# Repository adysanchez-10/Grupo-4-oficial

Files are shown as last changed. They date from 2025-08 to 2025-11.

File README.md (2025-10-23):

# Integrantes del Proyecto

## Camila Andrea Seijas Rojas
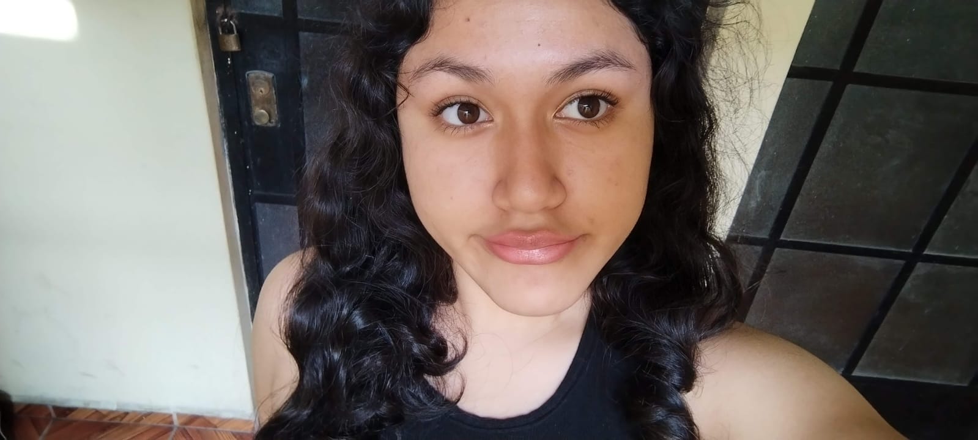
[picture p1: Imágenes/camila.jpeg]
## 
- **Edad:** 18 años  
- **Información personal:** Interés en el área de biomecánica y rehabilitación.  
- **Rol:** Investigación y redacción  
- **Responsabilidades:**
  - Seleccionar la información pertinente y necesaria  
  - Editar la información en GitHub  

---

## Milagros Mariajosé Rodriguéz Solano
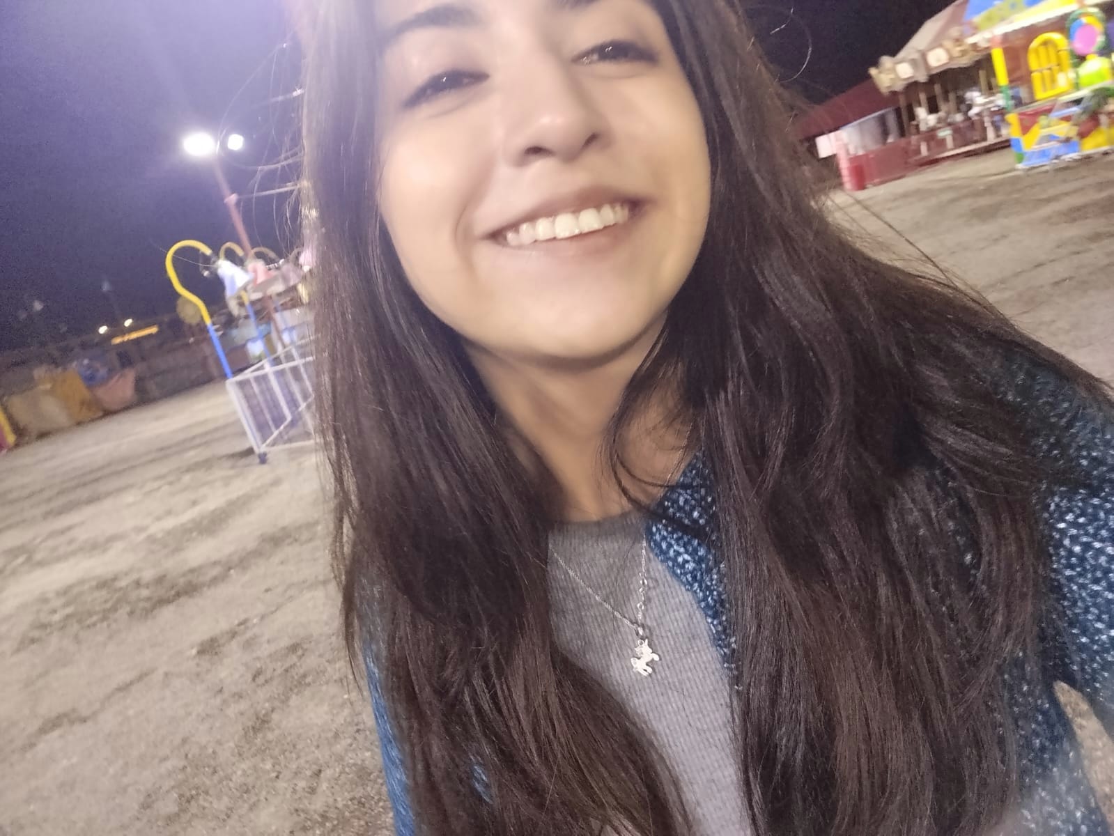
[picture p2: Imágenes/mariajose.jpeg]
## 
- **Edad:** 20 años  
- **Información personal:** Interés en el área de biomecánica y rehabilitación.  
- **Rol:** Modelador 3D  
- **Responsabilidades:**
  - Optimización de modelos  
  - Diseño y construcción de modelos 3D  

---

## Rodrigo Emiliano Salas Cano
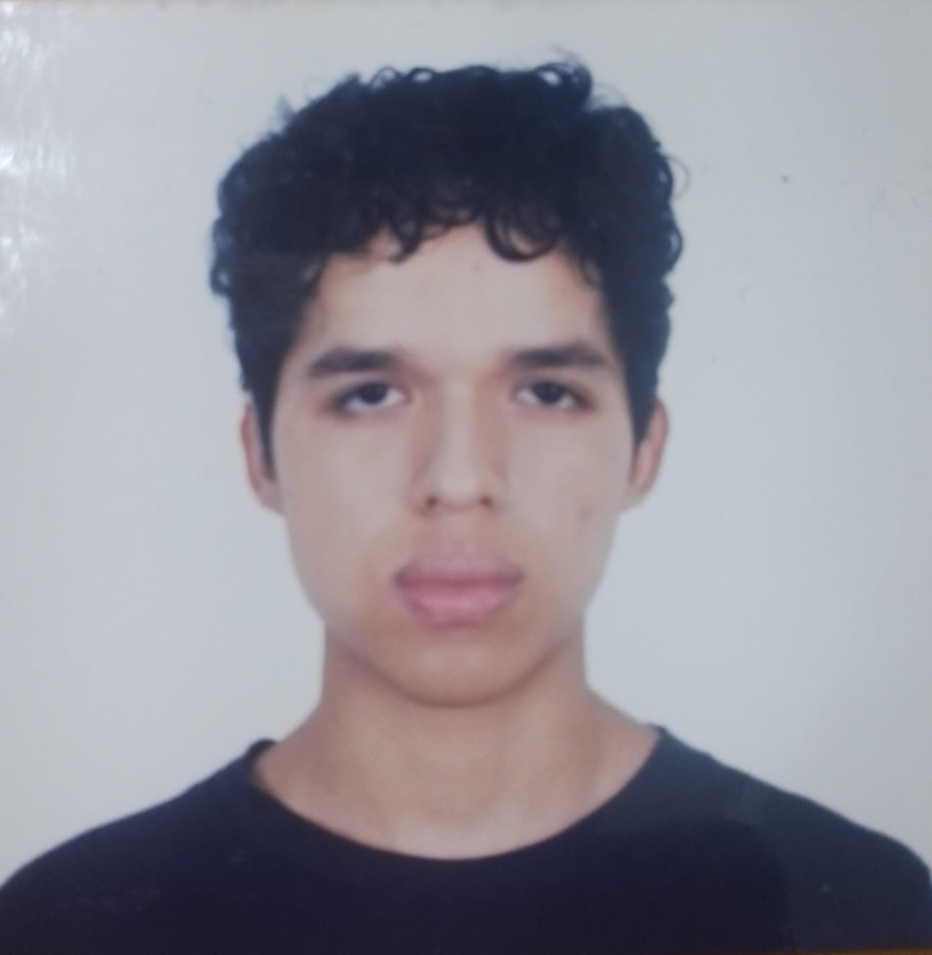
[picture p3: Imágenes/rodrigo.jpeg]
## 
- **Edad:** 18 años  
- **Información personal:** Interés en el área de tejidos.  
- **Rol:** Gestor de repositorio de GitHub  
- **Responsabilidades:**
  - Control de calidad del código  
  - Gestión de problemas  

---

## Gabriel Romero Guerrero
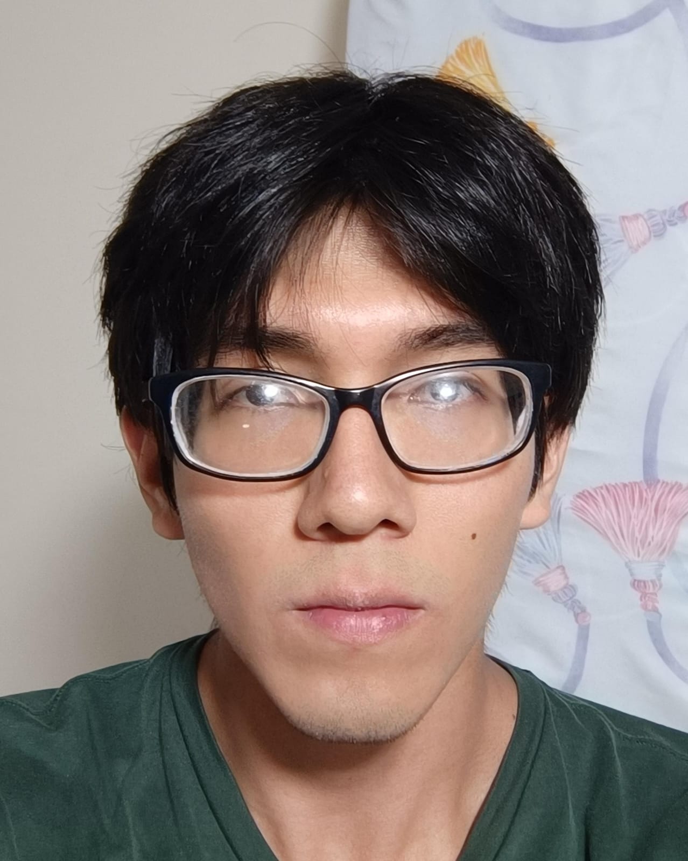
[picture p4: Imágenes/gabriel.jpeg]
## 
- **Edad:** 23 años  
- **Información personal:** Interesado en la aplicación de la tecnología para problemas biomecánicos y de diagnóstico.  
- **Rol:** Funcionamiento de la electrónica  
- **Responsabilidades:**
  - Cableado y conexionado  
  - Diseño y modificación de circuitos  

---
## Ady Sebastián Sánchez Guevara
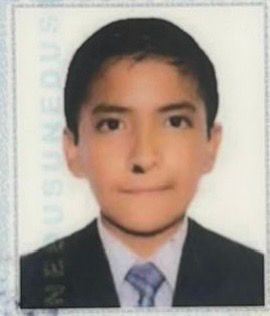
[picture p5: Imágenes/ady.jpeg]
## 
- **Edad:** 18 años  
- **Información personal:** Interés en el área de clínica.  
- **Rol:** Programación  
- **Responsabilidades:**
  - Crear las carpetas en GitHub  
  - Editar la información en GitHub  

---

## Leonardo Romani León}
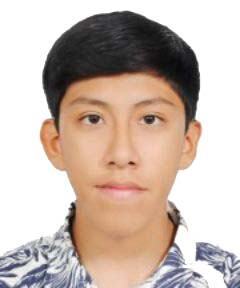
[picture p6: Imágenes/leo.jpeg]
## 
- **Edad:** 18 años  
- **Información personal:** Interés en el área de biomecánica en imágenes.  
- **Rol:** Programación y modelo 3D  
- **Responsabilidades:**
  - Elaboración de código para el funcionamiento del mecanismo  
  - Elaboración del modelado en 3D

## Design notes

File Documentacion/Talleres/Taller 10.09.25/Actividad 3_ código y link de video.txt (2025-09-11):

Link de video en Youtube: https://youtube.com/shorts/MGsZXVsQCxA?si=Kkdt9dwiiTKEzWkI

//inicio de código
#include <MPU6050.h>
#include <Wire.h>

MPU6050 mpu;

const int buzzerPin = 8;
const float g = 9.81;  // gravedad en m/s^2
const float umbralCaidaAlta = 2.0 * g;   // > 2g
const float umbralCaidaBaja = 0.5 * g;   // caída libre ~0.5g

bool alarmaActiva = false;
unsigned long tiempoInicioAlarma = 0;   
const unsigned long duracionAlarma = 2000; // 5 segundos

void setup() {
  Serial.begin(9600);
  Wire.begin();
  mpu.initialize();

  if (mpu.testConnection()) {
    Serial.println("MPU6050 conectado correctamente.");
  } else {
    Serial.println("Error al conectar MPU6050.");
  }

  pinMode(buzzerPin, OUTPUT);
  digitalWrite (8,HIGH);
}

void loop() {
  int16_t ax, ay, az;
  mpu.getAcceleration(&ax, &ay, &az);

  // Convertir a m/s^2 (rango configurado en ±2g)
  float ax_g = ax / 16384.0 * g;
  float ay_g = ay / 16384.0 * g;
  float az_g = az / 16384.0 * g;

  // Magnitud total de la aceleración
  float aTotal = sqrt(ax_g * ax_g + ay_g * ay_g + az_g * az_g);

  Serial.print("aTotal = ");
  Serial.println(aTotal);

  // Detectar caída y activar buzzer
  if (!alarmaActiva && (aTotal > umbralCaidaAlta || aTotal < umbralCaidaBaja)) { //alta 19.62 baja 4.9
    Serial.println("¡Caída detectada!");
    tone(buzzerPin, 3000);        // sonido de alerta
    alarmaActiva = true;
    tiempoInicioAlarma = millis(); // guardamos el momento
  }

  // Apagar buzzer después de 5 segundos
  if (alarmaActiva && (millis() - tiempoInicioAlarma >= duracionAlarma)) {
    noTone(buzzerPin);
    digitalWrite(8,HIGH);
    alarmaActiva = false;
    Serial.println("Alarma apagada automáticamente.");
  }
 
  delay(200);
}
//fin

3RO

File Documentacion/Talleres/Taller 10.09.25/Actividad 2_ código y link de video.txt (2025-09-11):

Link de video en Youtube: https://youtube.com/shorts/js4WZ6bAnnM?si=TciuPzV8fLwrm0xc

//inicio de código usado
// Pines de sensores
const int flexPin = A0;
const int fsr1Pin = A1;
const int fsr2Pin = A2;

// Pines de LEDs
const int ledVerde = 9;   // PWM
const int ledRojo = 8;
const int ledAmarillo = 7;

// Umbrales para los FSR (ajustar tras calibración)
const int umbralFSR1 = 300;  
const int umbralFSR2 = 300;  

void setup() {
  pinMode(ledVerde, OUTPUT);
  pinMode(ledRojo, OUTPUT);
  pinMode(ledAmarillo, OUTPUT);
  
  Serial.begin(9600);
}

void loop() {
  // Lecturas analógicas
  int flexValue = analogRead(flexPin);
  int fsr1Value = analogRead(fsr1Pin);
  int fsr2Value = analogRead(fsr2Pin);

  // --- LED verde con PWM proporcional a la flexión ---
  int brillo = map(flexValue, 0, 1023, 0, 255);
  analogWrite(ledVerde, brillo);

  // --- LED rojo controlado por FSR1 ---
  if (fsr1Value > umbralFSR1) {
    digitalWrite(ledRojo, HIGH);
  } else {
    digitalWrite(ledRojo, LOW);
  }

  // --- LED amarillo controlado por FSR2 ---
  if (fsr2Value > umbralFSR2) {
    digitalWrite(ledAmarillo, HIGH);
  } else {
    digitalWrite(ledAmarillo, LOW);
  }

  // Enviar datos al monitor serie
  Serial.print("Flex: "); Serial.print(flexValue);
  Serial.print(" | FSR1: "); Serial.print(fsr1Value);
  Serial.print(" | FSR2: "); Serial.println(fsr2Value);

  delay(50); // pequeña pausa
}
//fin

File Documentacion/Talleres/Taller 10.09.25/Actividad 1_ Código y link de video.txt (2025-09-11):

Link de video en Youtube: https://youtu.be/Luw4oxsUc28?si=Q1tBcIxFa8vk1GIK

//inicio de código utilizado
const int emgPin = A0;
const int ledpin = 13;
int umbral = 350;

void setup() {
  Serial.begin(9600);
  pinMode(ledpin, OUTPUT);
}

void loop() {
  int emgValue = analogRead(emgPin); // Lectura del sensor

  if (emgValue > umbral) {
    digitalWrite(ledpin, HIGH); // Enciende el LED si se supera el umbral
  } else {
    digitalWrite(ledpin, LOW);  // Apaga el LED si no se supera
  }

  Serial.print("EMG Value: ");
  Serial.println(emgValue);

  delay(100);
}
//fin

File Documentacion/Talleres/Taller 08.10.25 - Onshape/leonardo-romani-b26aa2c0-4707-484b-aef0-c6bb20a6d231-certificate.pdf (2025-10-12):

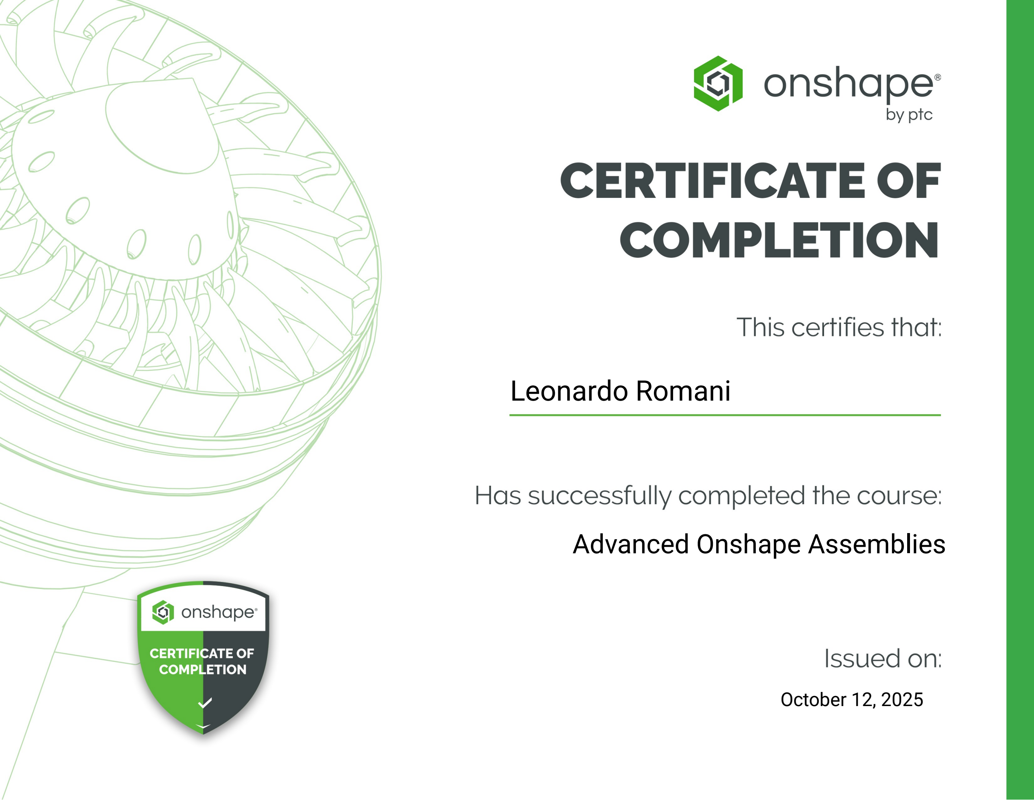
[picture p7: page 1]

Leonardo Romani

Advanced Onshape Assemblies

October 12, 2025

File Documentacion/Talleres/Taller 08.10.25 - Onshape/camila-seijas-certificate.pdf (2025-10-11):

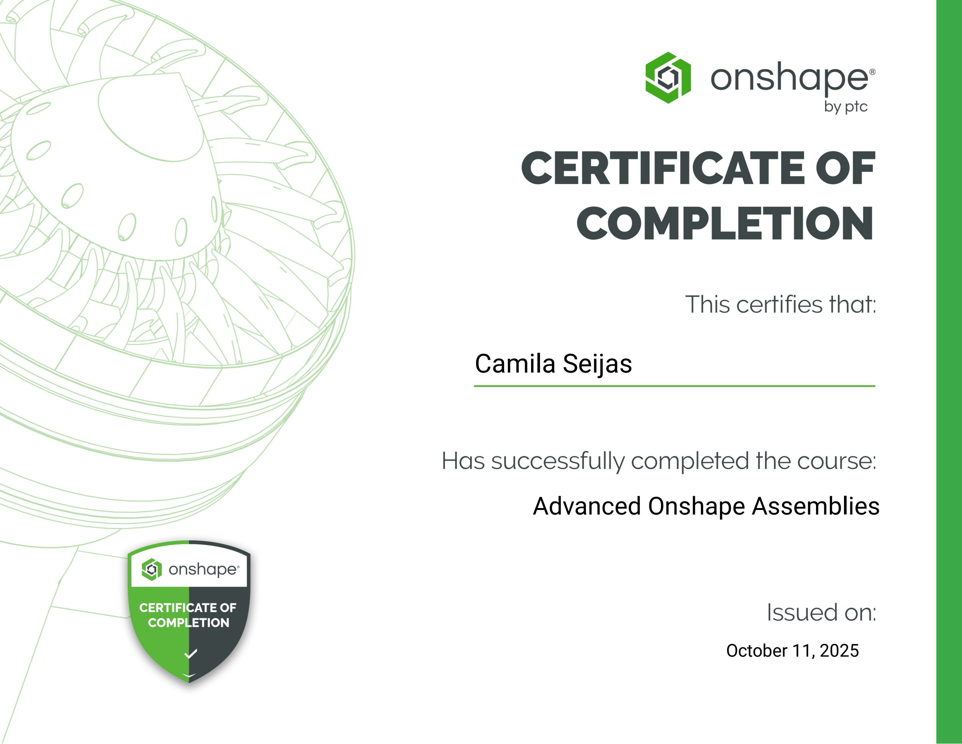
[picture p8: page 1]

Camila Seijas

Advanced Onshape Assemblies

October 11, 2025

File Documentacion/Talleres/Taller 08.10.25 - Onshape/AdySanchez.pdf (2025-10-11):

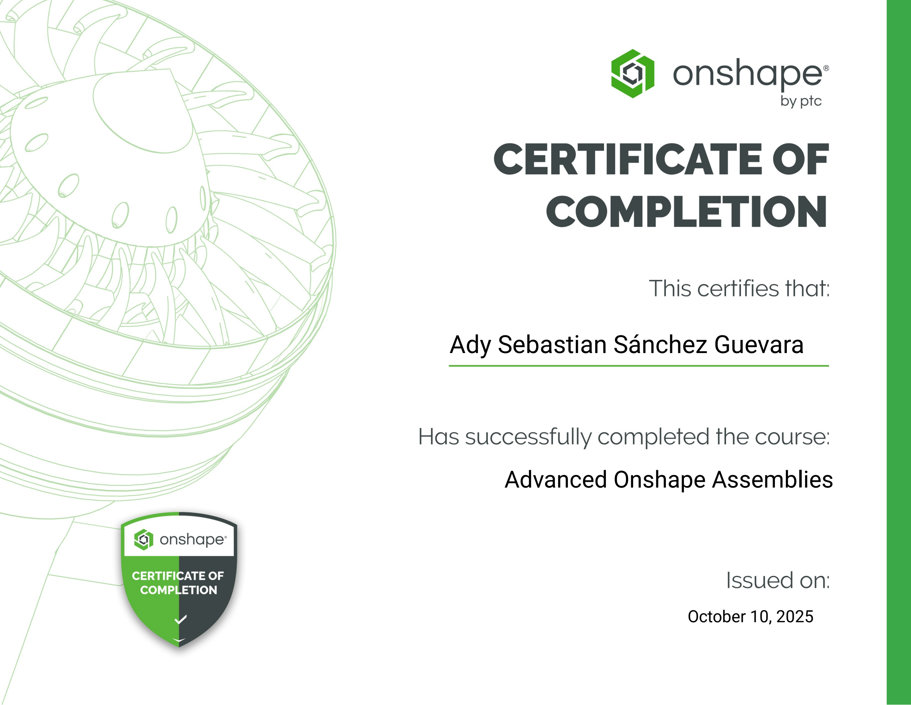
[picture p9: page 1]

Ady Sebastian Sánchez Guevara

Advanced Onshape Assemblies

October 10, 2025

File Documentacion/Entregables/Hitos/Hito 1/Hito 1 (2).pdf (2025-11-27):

# FOMEX Grupo 04

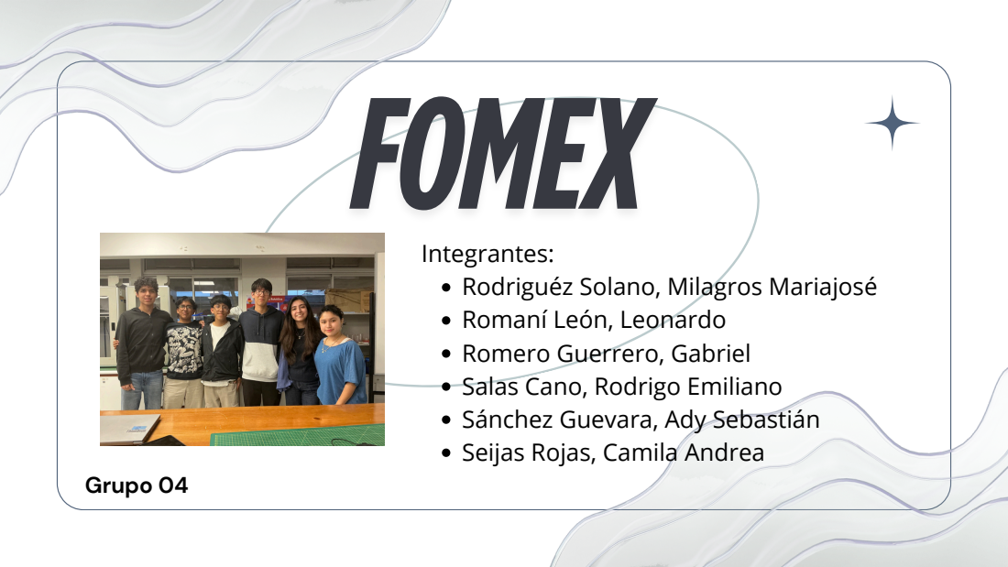
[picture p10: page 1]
s: Rodrigué; ola; Mila; ria; tiá; eij; mila

riel Salas Cano, Rodrigo Emilia

# CONTEXTO DEL CASO

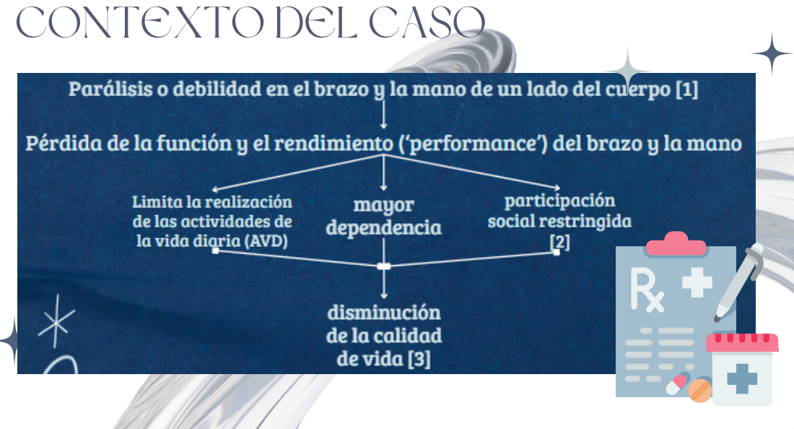
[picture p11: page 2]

# CONTEXTO DEL CASO

## 87 % de los pacientes reporta que experimenta al desuso de su mano y brazo afectado

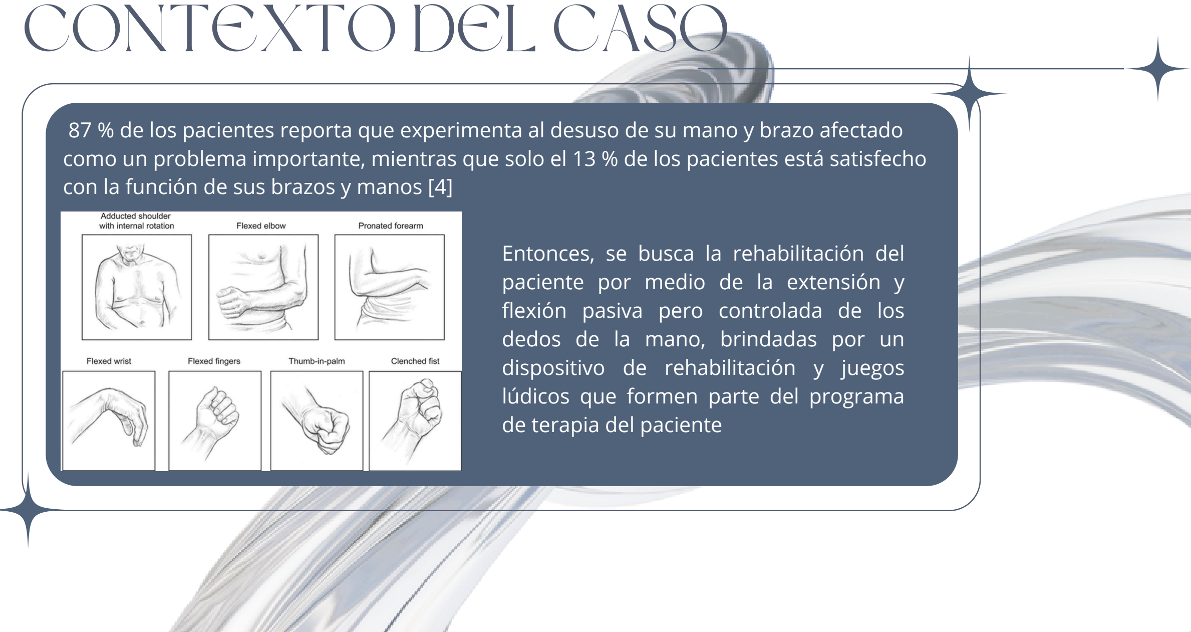
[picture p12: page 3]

## como un problema importante, mientras que solo el 13 % de los pacientes está satisfecho con la función de sus brazos y manos [4]

## Entonces, se busca la rehabilitación del paciente por medio de la extensión y flexión pasiva pero controlada de los dedos de la mano, brindadas por un dispositivo de rehabilitación y juegos lúdicos que formen parte del programa de terapia del paciente

# CONTEXTO DEL CASO

## Descripción del ACV:

## El Accidente Cerebrovascular (ACV), también conocido como ictus o derrame cerebral, es

una alteración súbita del flujo sanguíneo hacia una parte del cerebro.

## Cuando esto ocurre, las neuronas dejan de recibir oxígeno y nutrientes, provocando la

muerte de las células cerebrales en pocos minutos [5].

## Descripción del caso: Paciente femenina de 55 años con hemiplejia espástica derecha post-ACV

## Presenta leve disartria y marcha insegura (deambula con bastón de 4 apoyos) Comprensión y cognición conservadas

Funcionalidad completa del hemicuerpo izquierdo [6].

## Rehabilitación:

## Terapia física, 3 veces por semana (ejercicios de movilidad, estiramientos y reeducación

de la marcha).
Terapia de lenguaje, 1 vez por semana (manejo de disartria leve) [6].

# ESTADO DEL ARTE

# 1.PATENTE: Órtesis robótica PRO-DWix® (PCT/CO2017/000006)

Objetivo:
Complementar la rehabilitación y mejorar la adherencia de los pacientes con espasticidad de mano post ACV o tras una lesión medular con un dispositivo para uso domiciliario

## Funcionamiento: El dispositivo mueve la mano del paciente mediante un sistema de servomotores y piezas articuladas que actúan como un exoesqueleto

Motores en la Mano: Sobre el dorso de la
mano del paciente se colocan unos servomotores.
Sistema de Palancas: Cada servomotor está conectado a un sistema de palancas hechas de acrílico. Estas palancas están unidas a los dedos del paciente mediante unas correas. Acción de Flexión y Extensión: Cuando los motores se activan, giran y mueven la primera palanca. Este movimiento se transmite a las otras piezas articuladas, obligando a los dedos a doblarse (flexión) y estirarse (extensión) de manera controlada y armónica, imitando el movimiento natural de las articulaciones.

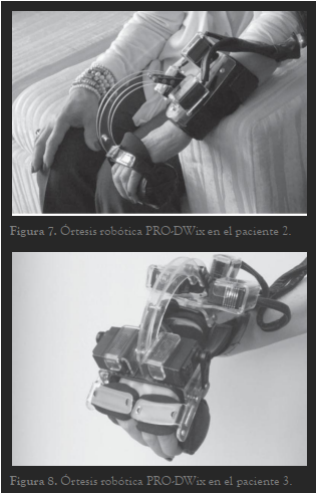
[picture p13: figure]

Fuentes:

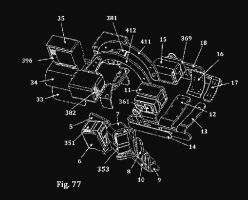
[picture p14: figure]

[7] J. D. Moreno Arango and J. A. Moreno Arango, "Ortesis robóticas para rehabilitación de mano y muñeca," PCT Int. Appl. WO 2018/036571 A1, Mar. 1, 2018.
[8] J. F. Gómez-Rendón, J. D. Moreno-Arango, J. M. Medina-Salcedo, J. Becerra-Velásquez, G. A. Gil-Henao, and M. A. Gil-Guerrero, "Rehabilitación robótica en espasticidad de mano y muñeca," Rev. Col. Med. Fis. Rehab., vol. 30, no. 2, pp. 103-115, 2020. doi: 10.28957/rcmfr.v30n2.

# 2. PROTOTIPO BASADO EN ARTÍCULO CIENTÍFICO: DexoHand

Objetivo:
Complementar la rehabilitación de los pacientes con espasticidad de mano post ACV Sistema de accionamiento por cables: aligera el peso (recomendación de 230 g a menos de masa sobre la mano [9])
Movimiento Anatómicamente Preciso: El exoesqueleto está diseñado para que sus centros de rotación virtual coincidan con las articulaciones reales de los dedos del paciente (MCP, PIP, DIP).

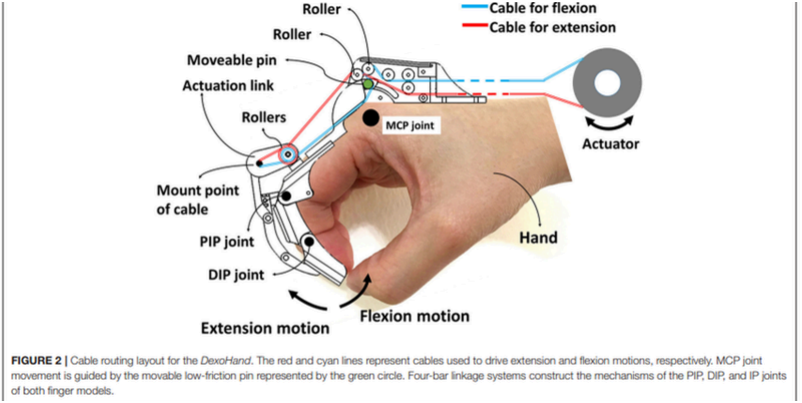
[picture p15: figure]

Fuente: [9] Y.-L. Tsai et al., "Usability Assessment of a Cable-Driven Exoskeletal Robot for Hand Rehabilitation," Front. Neurorobot., vol. 13, Art. no. 3, Feb. 2019, doi: 10.3389/fnbot.2019.00003.

### “Los cables eran accionados por un servomotor (motor BLDC, fuerza = 0,014

N-m, Faulhaber GmbH & Co. KG,

### Schönaich, Alemania) acoplado a un desacelerador (relación de transmisión = 1:100). A través del desacelerador, el

## torque de salida (con respecto a las articulaciones MCP de cada dedo) podía alcanzar hasta 1,4 N-m, lo que producía

### una fuerza de flexión y extensión correspondiente de 145 y 112 N. Según nuestras estimaciones, este nivel de

## fuerza pico es adecuado para manipular los dedos con MAS ≦ 3.”

## Torque pico de salida (con respecto a las articulaciones MCP de cada dedo) debe alcanzar hasta 1,4 Nm para manipular los dedos de manos con MAS ≦ 3, como la paciente del caso

## No extiende el pulgar

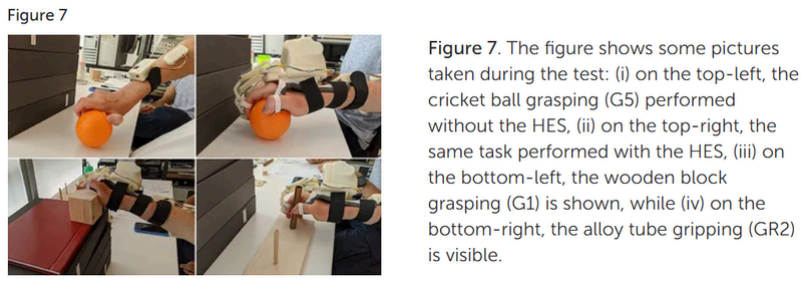
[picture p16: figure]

## Estructura rígida de impresión en 3D

## Accionamiento por Cables (Sistema de Tendones)

### Movimiento generado por

### cinco servomotores

### ubicados en una unidad de control separada que se lleva

### en la cintura

## Reducción de peso

Motores tiran de cables
Bowden (tendones
artificiales) que recorren el antebrazo hasta el
exoesqueleto para mover
los dedos.

# 3. PROTOTIPO BASADO EN ARTÍCULO CIENTÍFICO: Hand Exoskeleton System (HES)

Dos objetivos:
1. Asistencia: Ayudar a personas con debilidad muscular a agarrar y sostener objetos en sus actividades diarias, como sostener un vaso o un tenedor.
2. Rehabilitación: Guiar la mano del paciente a través de movimientos repetitivos y controlados para promover la recuperación motora.

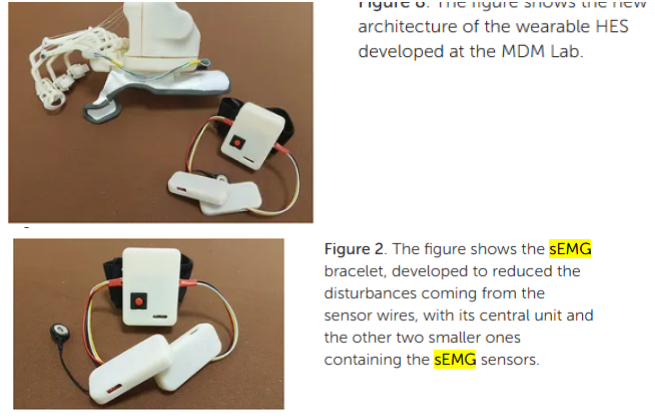
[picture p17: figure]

Fuente: [10] L. Secciani, A. Brogi, M. Pagliai, M. Buonamici, F. Gerli, F. Vannetti, E. Bianchini, Y. Volpe, and A. Ridolfi, "Wearable robots: An original mechatronic design of a hand exoskeleton for assistive and rehabilitative purposes," Frontiers in Neurorobotics, vol. 15, pp. 1–16, 2021, doi: 10.3389/fnbot.2021.750385.

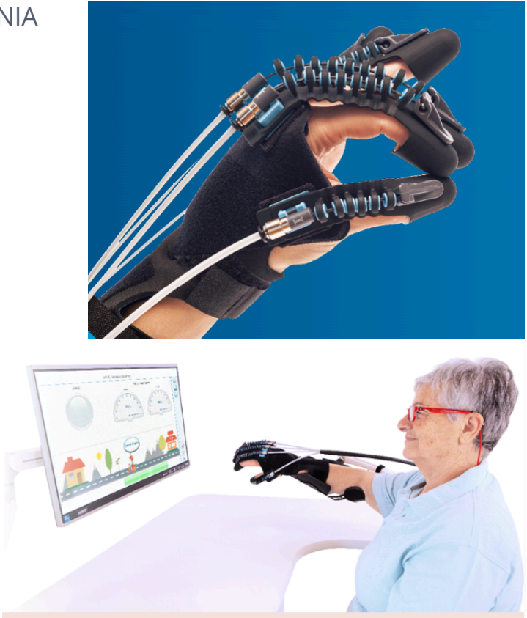
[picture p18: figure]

# 4. PRODUCTO COMERCIAL: GLOREHA SINFONIA

## Guante de robótica suave que apoya la apertura y cierre de la mano

### Motores ubicados en una consola externa, reduce peso

### Múltiples modos de Terapia: Ofrece programas de movilización

### pasiva, terapia activo-asistida y entrenamiento bimanual

### (terapia de espejo), donde la mano sana guía a la mano

afectada.

Dispositivo no usa sEMG, pero puede detectar mediante sensores no especificados el movimiento físico que inicia el paciente y asistirlo entonces de manera parcial o total

Estimulación Multisensorial: Los ejercicios se combinan con animaciones 3D y efectos de sonido para aumentar la implicación del paciente y la estimulación cerebral.

Fuente: [11] Gloreha, “Gloreha Sinfonia — robotic glove for hand rehabilitation,” Gloreha IDROGENET, Lumezzane, Italy. ⟨Online. Available: https://www.gloreha.com/r-touch-pro-sinfonia/⟩

## Niveles de espasticidad que deben tener los pacientes para uso del dispositivo no son mencionados

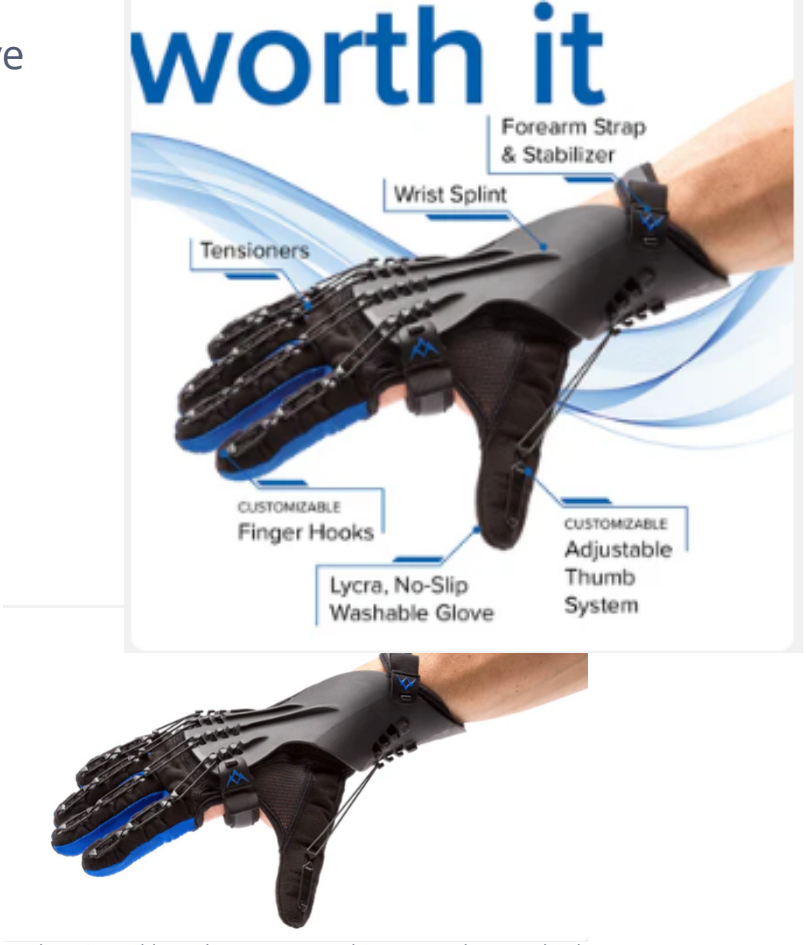
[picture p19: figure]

# 5. PRODUCTO COMERCIAL: SaeboGlove

## Exoesqueleto de mano mecánico No utiliza motores ni componentes

electrónicos.

## Su función principal es asistir la

apertura de la mano.

## El paciente utiliza su propia fuerza muscular para cerrar la mano y agarrar

un objeto.

## Uso Doméstico: Su simplicidad y bajo costo lo hacen ideal para programas de

## rehabilitación en el hogar, permitiendo un alto volumen de repeticiones de tareas

funcionales.

## Indicado solamente para bajos niveles de espasticidad (MAS<=1+)

Fuente: [12] Saebo, “SaeboGlove Hand Therapy Rehabilitation Glove,” Saebo, Disponible en: https://www.saebo.com/products/saeboglove?srsltid=AfmBOoq1vsaCfwpBxVvEY5KIptrD9_bhrRYAByg85I8YhKfe7A9JqTtG&

# REQUERIMIENTOS FUNCIONALES

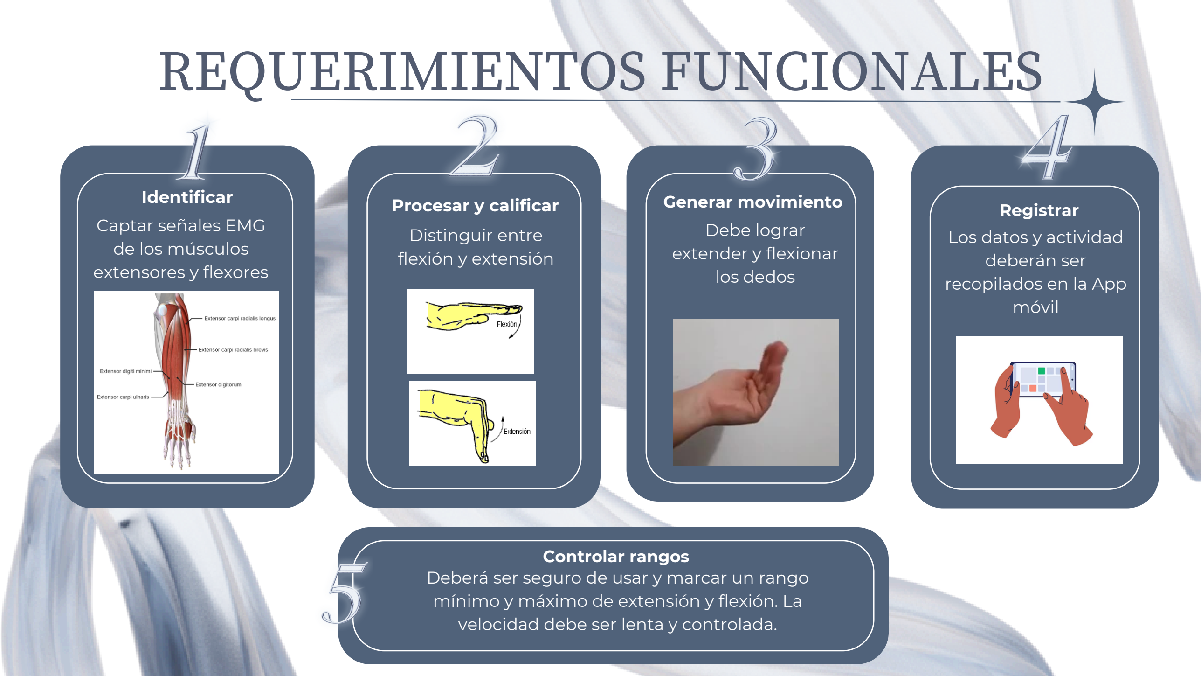
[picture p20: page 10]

Identificar | Procesar y calificar | Generar movimiento | Registrar
| Distinguir entre flexión y extensión | Debe lograr extender y flexionar los dedos | Los datos y actividad deberán ser recopilados en la App móvil

Controlar rangos
Deberá ser seguro de usar y marcar un rango mínimo y máximo de extensión y flexión. La velocidad debe ser lenta y controlada.

Captar señales EMG
de los músculos
extensores y flexores

# REQUERIMIENTOS NO FUNCIONALES

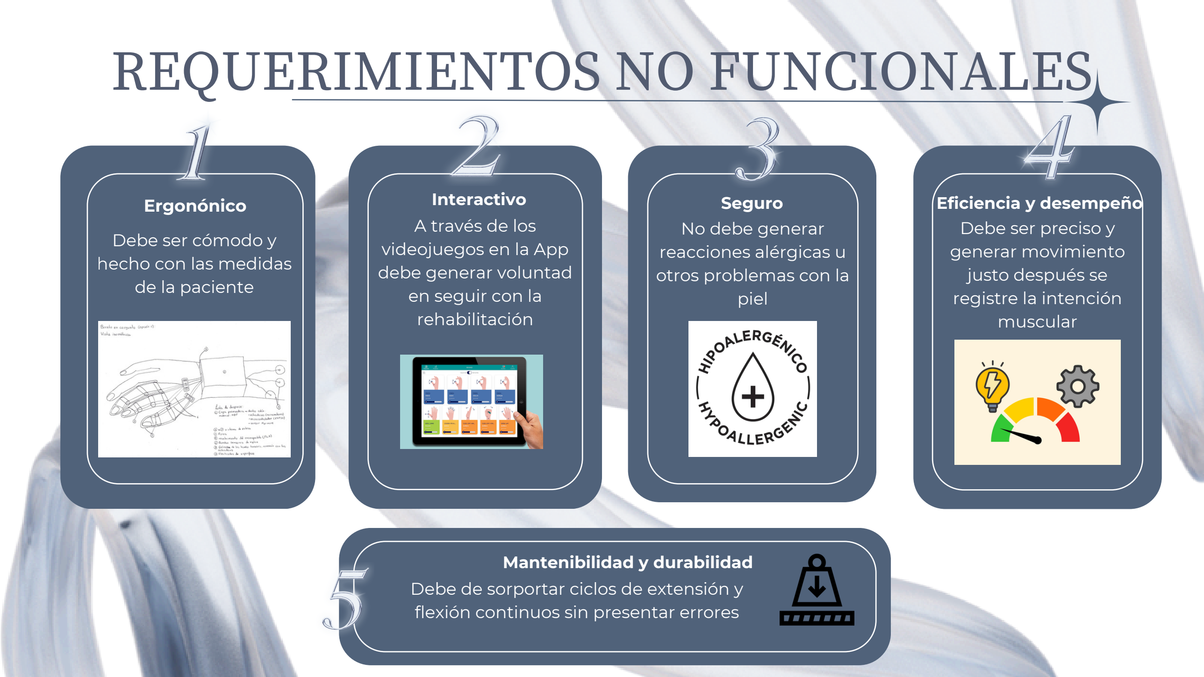
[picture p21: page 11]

Ergonónico | Seguro | Eficiencia y desempeño

Mantenibilidad y durabilidad

Debe ser cómodo y
hecho con las medidas
de la paciente

Interactivo
A través de los
videojuegos en la App
debe generar voluntad
en seguir con la
rehabilitación

No debe generar
reacciones alérgicas u
otros problemas con la
piel

Debe ser preciso y
generar movimiento
justo después se
registre la intención
muscular

Debe de sorportar ciclos de extensión y flexión continuos sin presentar errores

# CAJA NEGRA

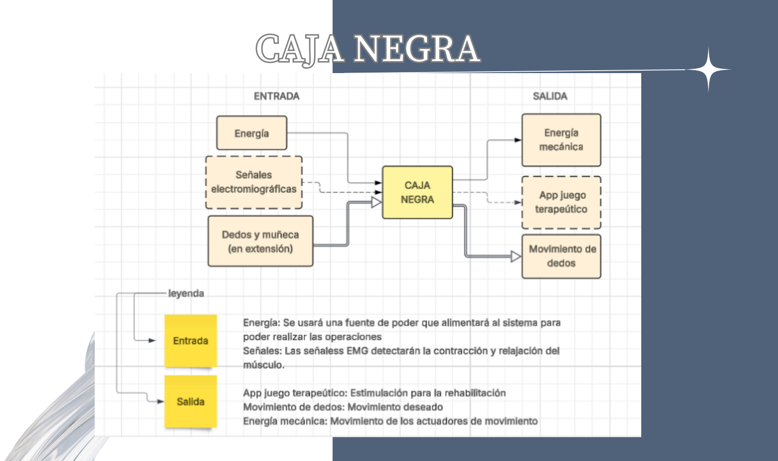
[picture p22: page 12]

# ESTRUCTURA DE FUNCIONES

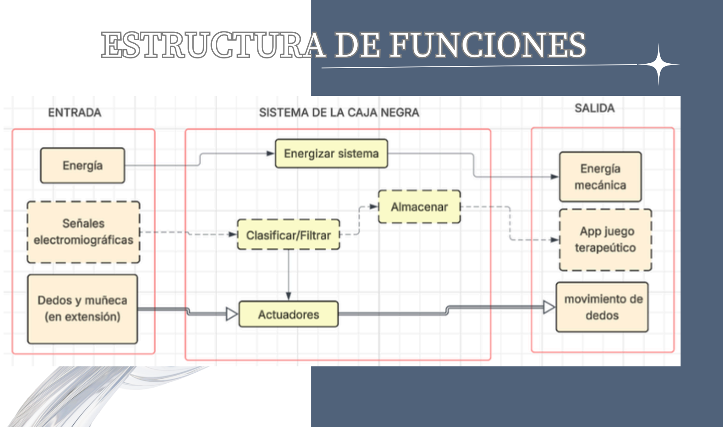
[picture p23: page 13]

# MATRIZ

# MORFOLÓGICA

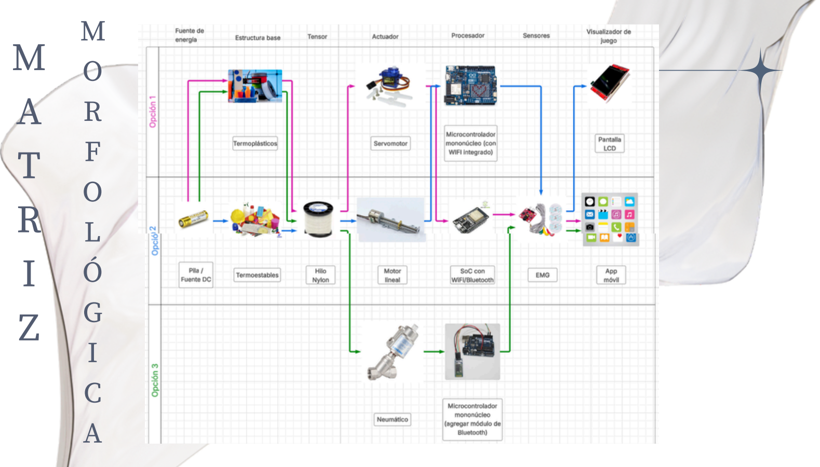
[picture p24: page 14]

# Detalles técnicos sobre el movimiento de extensión de los dedos

Los informes indican un aumento de la rigidez articular proporcional al MAS, con un MAS = 3 que

## promedia ≈ 0,63 N.m/rad (rigidez) para los flexores de los dedos [13]

## Si asumimos que la mano espástica de la paciente suele estar flexionada entre 30° a 60°

## , que equivale a 0.52 rad a 1.05 rad: Torque buscado = k × θ = 0.63 × (0.52 a 1.05) = 0.33 a 0.66 N.m

## Entonces, concluimos que se deben usar entre 0.3 a 0.7 N.m (redondeando) continuos en la extensión de los dedos y y 1,4 N.m (caso extremo) como torque máximo con respecto a cada

articulación MCP.

# Luego, si se supone una velocidad angular de flexión de 10 a 100°/s , que son 0.1745

# a 1.745 rad/s, entonces Potencia (P) = Torque (τ) X velocidad angular (w)

# Pmin=0.3×0.1745=0.052 W

# Pmedio=0.5×0.96(velocidad promedio)≈0.48W Pmax=0.7×1.745=1.2215 W

[13] C. J. W. Haarman, E. E. G. Hekman, J. S. Rietman, and H. Van Der Kooij,

“Mechanical Design and Feasibility of a Finger Exoskeleton to Support Finger Extension of Severely Affected Stroke Patients,

” IEEE Trans. Neural Syst. Rehabil. Eng., vol. 31, pp. 1268-1276, 2023, doi: 10.1109/TNSRE.2023.3243357.

# Ppico=1.4×0.96=1.344 W Ppico max=1.4×1.745=2.443 W CONCLUSIÓN: Microservos o servos de baja potencia (<5 W)

# TABLA DE VALORACIÓN

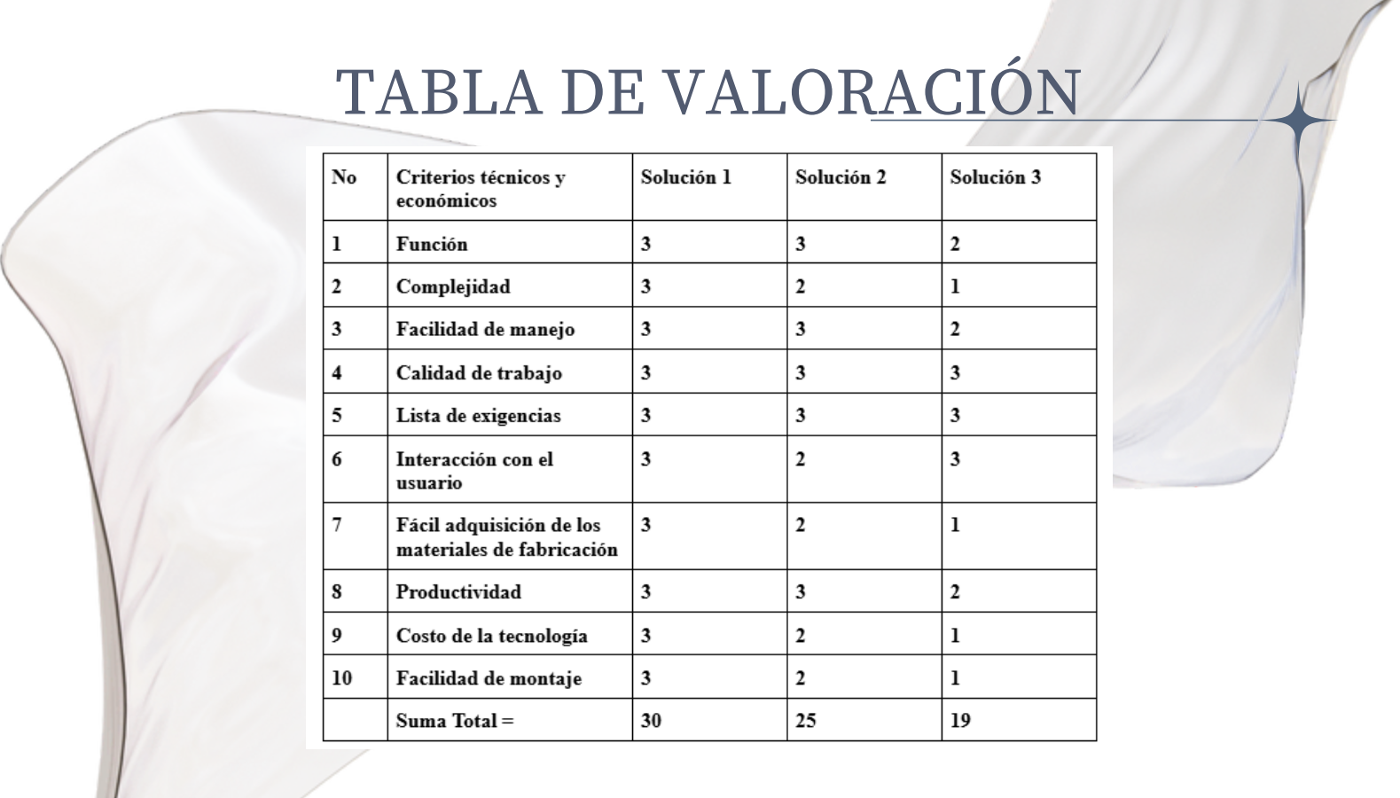
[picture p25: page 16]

# BOCETOS

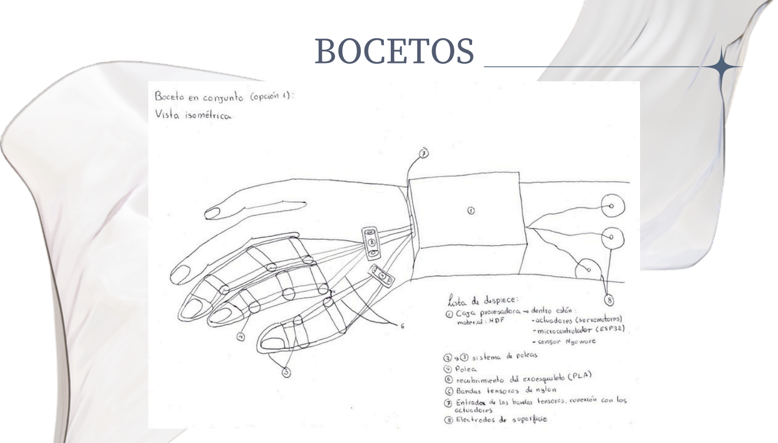
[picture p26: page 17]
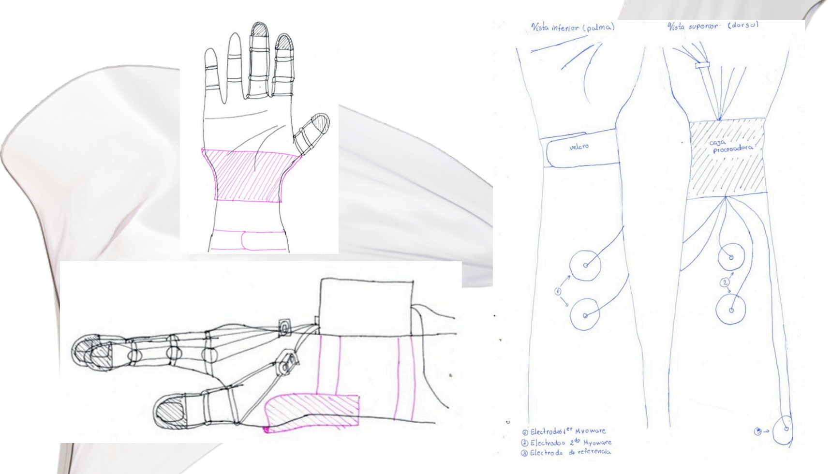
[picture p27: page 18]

# ONCLUSIONES

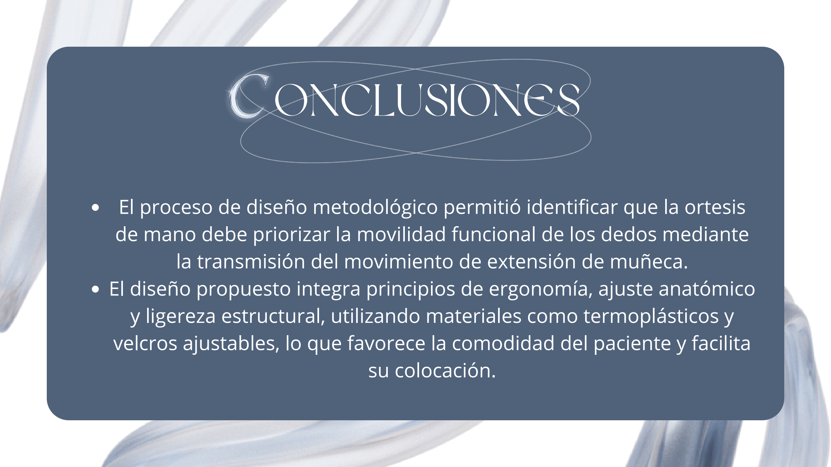
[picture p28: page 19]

# El proceso de diseño metodológico permitió identificar que la ortesis de mano debe priorizar la movilidad funcional de los dedos mediante

la transmisión del movimiento de extensión de muñeca.

# El diseño propuesto integra principios de ergonomía, ajuste anatómico y ligereza estructural, utilizando materiales como termoplásticos y velcros ajustables, lo que favorece la comodidad del paciente y facilita

su colocación.

# EFERENCIAS IBLIOGRÁFICAS:

[1] Huang, J., Ji, J., Liang, C., Zhang, Y., Sun, H., Yan, Y., & Xing, X.,

“Effects of physical therapy-based rehabilitation on recovery of upper limb motor function after stroke in adults: a systematic review and meta-analysis of randomized controlled trials.”

, Ann.
Palliat. Med., vol. 11, núm. 2, pp. 521–531, 2021, doi: https://doi.org/10.21037/apm-21-3710.
[2] Li, S., Francisco, G., & Zhou, P.,

“Post-stroke Hemiplegic Gait: New Perspective and Insights.”

, Front. Physiol., vol. 9, 2018, doi: https://doi.org/10.3389/fphys.2018.01021.
[3] Anwer, S., & Alghadir, A.,

“Incidence, Prevalence, and Risk Factors of Hemiplegic Shoulder Pain: A Systematic Review.”

, Int. J.
Environ. Res. Public. Health, vol. 17, 2020, doi: https://doi.org/10.3390/ijerph17144962.
[4] Gavesh Kumar Vaishnav; Janardan Patra.,

“Comparison of Quality of Life Between Right and Left Hemiplegic Stroke Population: A Cross-Sectional Study.”

, Int. J. Innov. Sci. Res. Technol., vol. 10, núm. 5, pp. 337–343, may 2025, doi: https://doi.org/10.38124/ijisrt/25may170.
[5]«Accidente cerebrovascular: MedlinePlus enciclopedia médica». Accedido: 15 de octubre de 2025. [En línea]. Disponible en: https://medlineplus.gov/spanish/ency/article/000726.htm
[6] Universidad Peruana Cayetano Heredia, Caso clínico: ACV, presentación en PowerPoint, curso de Fundamentos de Biodiseño , Lima, Perú, 2025.
[7] J. D. Moreno Arango and J. A. Moreno Arango,

"Ortesis robóticas para rehabilitación de mano y muñeca,

" PCT Int. Appl. WO
2018/036571 A1, Mar. 1, 2018.

# EFERENCIAS

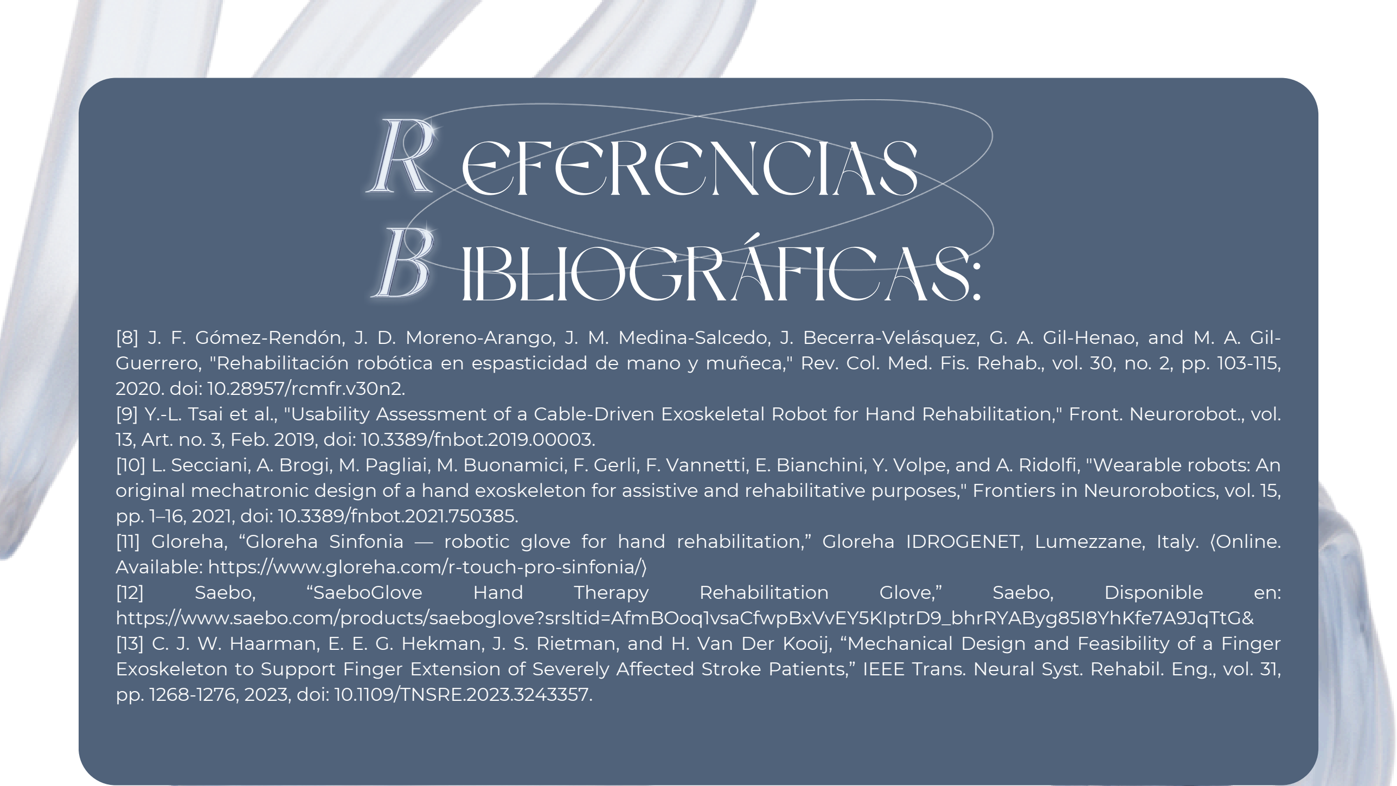
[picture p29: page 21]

# IBLIOGRÁFICAS:

[8] J. F. Gómez-Rendón, J. D. Moreno-Arango, J. M. Medina-Salcedo, J. Becerra-Velásquez, G. A. Gil-Henao, and M. A. Gil-Guerrero,

"Rehabilitación robótica en espasticidad de mano y muñeca,

" Rev. Col. Med. Fis. Rehab., vol. 30, no. 2, pp. 103-115, 2020. doi: 10.28957/rcmfr.v30n2.
[9] Y.-L. Tsai et al.,

"Usability Assessment of a Cable-Driven Exoskeletal Robot for Hand Rehabilitation,

" Front. Neurorobot., vol. 13, Art. no. 3, Feb. 2019, doi: 10.3389/fnbot.2019.00003.
[10] L. Secciani, A. Brogi, M. Pagliai, M. Buonamici, F. Gerli, F. Vannetti, E. Bianchini, Y. Volpe, and A. Ridolfi,

"Wearable robots: An
original mechatronic design of a hand exoskeleton for assistive and rehabilitative purposes,

" Frontiers in Neurorobotics, vol. 15, pp. 1–16, 2021, doi: 10.3389/fnbot.2021.750385.
[11] Gloreha,

“Gloreha Sinfonia — robotic glove for hand rehabilitation,

” Gloreha IDROGENET, Lumezzane, Italy. ⟨Online. Available: https://www.gloreha.com/r-touch-pro-sinfonia/⟩
[12] Saebo,
“SaeboGlove | Hand | Therapy | Rehabilitation | Glove,
” | Saebo, | Disponible | en:
https://www.saebo.com/products/saeboglove?srsltid=AfmBOoq1vsaCfwpBxVvEY5KIptrD9_bhrRYAByg85I8YhKfe7A9JqTtG&
[13] C. J. W. Haarman, E. E. G. Hekman, J. S. Rietman, and H. Van Der Kooij,
| | | | “Mechanical Design and Feasibility of a Finger
Exoskeleton to Support Finger Extension of Severely Affected Stroke Patients,
| | | | ” IEEE Trans. Neural Syst. Rehabil. Eng., vol. 31,
pp. 1268-1276, 2023, doi: 10.1109/TNSRE.2023.3243357.

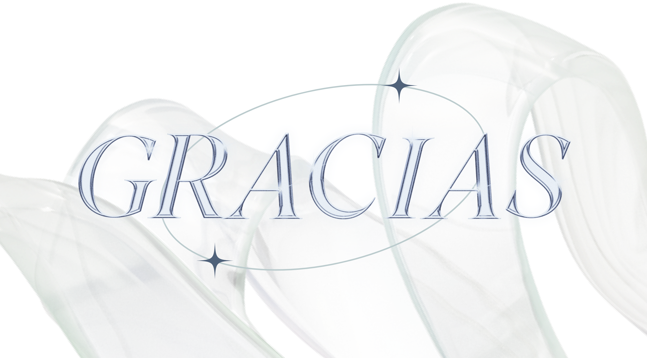
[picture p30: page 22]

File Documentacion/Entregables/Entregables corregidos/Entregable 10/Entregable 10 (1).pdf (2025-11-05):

"Año de la recuperación y consolidación de la economía peruana"

## Universidad Peruana Cayetano Heredia - Pontificia Universidad Católica del Perú


## Facultad De Ciencias E Ingeniería Ingeniería Biomédica

Décimo entregable
“Prototipado electrónico 2. Animación 3D y fabricación digital de componentes. Plan de usabilidad basado en evidencias” Integrantes:
Rodriguéz Solano, Milagros Mariajosé Romaní León, Leonardo
Romero Guerrero, Gabriel
Salas Cano, Rodrigo Emiliano Sánchez Guevara, Ady Sebastián Seijas Rojas, Camila Andrea Cuarto ciclo
Profesores:
Miguel Rogger Hoyos Alvitez Marco Mugaburu Celi|
Shirley Pahuachon Nuñez
Fecha de entrega: 04/11/2025

### 1. Prototipado electrónico:


Figura 1: Armado electrónico y adaptado

Código:

#include <ESP32Servo.h>

#include "BluetoothSerial.h"

#define EMG1_PIN 34

#define EMG2_PIN 35

#define LED1_PIN 14

#define LED2_PIN 12

#define SERVO1_PIN 18

#define SERVO2_PIN 19

#define SERVO3_PIN 21

#define SERVO4_PIN 22

#define SERVO5_PIN 23

BluetoothSerial SerialBT;
Servo servo1, servo2, servo3, servo4, servo5;

int estadoActual = 0;
int umbral1 = 1800;
int umbral2 = 1800;
int angulo_inicial = 90;
int angulo_flexion = 130;
int angulo_extension = 60;

void moverServos(int angulo) {

servo1.write(angulo);
servo2.write(angulo);
servo3.write(angulo);
servo4.write(angulo);
servo5.write(angulo);
}

void setup() {
Serial.begin(115200);
SerialBT.begin("ESP32_EMG"); pinMode(LED1_PIN, OUTPUT); pinMode(LED2_PIN, OUTPUT); digitalWrite(LED1_PIN, HIGH);

servo1.setPeriodHertz(50); servo2.setPeriodHertz(50); servo3.setPeriodHertz(50); servo4.setPeriodHertz(50); servo5.setPeriodHertz(50);

servo1.attach(SERVO1_PIN); servo2.attach(SERVO2_PIN); servo3.attach(SERVO3_PIN); servo4.attach(SERVO4_PIN); servo5.attach(SERVO5_PIN);

moverServos(angulo_inicial); estadoActual = 0;
Serial.println("Sistema iniciado."); }

void loop() {
emg1 = analogRead(EMG1_PIN);
emg2 = analogRead(EMG2_PIN);

Serial.print("EMG1 (Flexor): "); Serial.print(emg1); Serial.print(" / EMG2 (Extensor): "); Serial.println(emg2);

if (emg1 > umbral1 && emg1 > emg2) {
if (estadoActual != 1){
moverServos(angulo_flexion); estadoActual = 1;
}
}
else if (emg2 > umbral2 && emg2 > emg1) { if(estadoActual != 2){
moverServos(angulo_extension); estadoActual = 2;

}
}
else {
if (estadoActual != 0){
moverServos(angulo_inicial); estadoActual = 0;
}
}

if (SerialBT.hasClient()) { digitalWrite(LED2_PIN, HIGH); }
else {
digitalWrite(LED2_PIN, LOW); }

delay(40);
}

Referencia de ángulos:

[1] A. F. Corredor Ávila, “Prótesis de Mano Robótica a Bajo Costo para Pacientes con Amputación del Miembro Superior,” Revista Innovación Digital y Desarrollo Sostenible – IDS, vol. 4, no. 2, pp. 81–95, Mar. 2024. [En línea]. Disponible en: https://revistas.iudigital.edu.co/index.php/ids/article/view/139
2. Avance de Fabricación Digital

3. Foto del prototipo y del despiece de sus componentes principales


### 4. Modelado de piezas en 3D:

- Caja procesadora (Ensamblaje incluyendo holders y componentes):

Link:
https://cad.onshape.com/documents/359ccaa65875d5055d36d1b1/w/b8097a02f1b9163722c6bd12/e/75ef76de7c4566abe43d0986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 d0ac219fab868f (https://cad.onshape.com/documents/359ccaa65875d5055d36d1b1/w/b8097a02f1b9163722c6bd12/e/75ef76de7c4566abe43d0986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)
- Soporte para muñeca (Impresión 3D):

Link:
https://cad.onshape.com/documents/93b90db259101b59a2de45c1/w/74b02c7e41af1e7c9447220f/e/d0570645a6ee6a5de2919b3f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 a131814724bbb0 (https://cad.onshape.com/documents/93b90db259101b59a2de45c1/w/74b02c7e41af1e7c9447220f/e/d0570645a6ee6a5de2919b3f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)

- Ensamblaje y planos de las piezas de dedo junto con pieza del dorso del exoesqueleto


Link:
https://cad.onshape.com/documents/965afee487fad50ca48b4388/w/640c8db572ab4319f681f7ea/e/410b77d1d8a864f45ed70f66 (https://cad.onshape.com/documents/965afee487fad50ca48b4388/w/640c8db572ab4319f681f7ea/e/410b77d1d8a864f45ed70f66)

PLAN DE USABILIDAD:

### 1. Contexto de uso:

El dispositivo que se plantea desarrollar supone un diseño para pacientes con alteraciones motoras en la mano derecha por hemiplejía producto de alguna alteración neurológica con un grado de espasticidad de Ashworth 3. Está enfocado en la rehabilitación en casa con previa instrucción de uso por parte del terapista. Para el uso se insertan los dedos dentro de los recubrimientos de los dedos, también se coloca y se ajusta a la medida del paciente el soporte para muñeca y la caja electrónica por medio de velcros, luego se colocan los electrodos en los músculos flexores (musculus flexor digitorum superficialis) y extensores (musculus extensor digitorum). Finalmente debemos encender el switch de nuestra caja y esperar la conexión con la aplicación móvil.

### 2. Perfil del usuario:

Paciente femenino de 55 años de edad con hemiplejía espástica derecha post-ACV, mantiene la muñeca y los dedos en flexión permanente. Tiene dificultad para movilizarse y realizar actividades de vida diaria (AVD) de manera autónoma. Antes del episodio de ACV la paciente era costurera. Presenta señales mioeléctricas detectables por los sensores en los músculos flexores y extensores del antebrazo. Conserva el rango de movimiento pasivo completo en flexión, sin embargo, en extensión puede llegar como máximo a 170°. La paciente requiere que el movimiento que se realice sobre su mano al extender o flexionar sea lento y controlado para evitar espasmos. La paciente no logra movimiento de pinza fina ni de agarre funcional.

Datos de la paciente:
- Accidente cerebrovascular hace 6 meses
- Lúcida, presenta disartria leve
- Hemiplejía derecha con espasticidad de grado 3 en la escala de Ashworth
- Propiocepción alterada
- Rango de movimiento pasivo:
- Flexión: Completo
- Extensión: 170° aproximadamente

### 3. Análisis de tareas:

Tarea para uso | ¿Tarea crítica? | Justificación
Colocar los recubrimientos de los dedos y el dorso de la mano | Sí | En caso se coloquen mal los recubrimientos puede causar dolor en la paciente y/o generar un rango de movimiento erróneo
Ajustar con los velcros el soporte para la muñeca | Sí | Si se realiza mal generará dolor en la paciente y la caja electrónica podría caer.

Limpiar la zona y colocar los electrodos sobre los músculos flexores y extensores del antebrazo | Sí | Si no se limpia la zona y/o ubican correctamente los electrodos, la señal que captará el sensor podría ser errónea y generar movimiento alterado.
Presionar el switch de encendido | No | -
Acceder a la aplicación móvil | No | -
Realizar el calibrado de acuerdo a las señales captadas por los sensores mioeléctricos | Sí | No realizar adecuadamente la calibración podría ocasionar alteraciones en los rangos y tipos de movimientos.
Acceder al juego disponible en la aplicación móvil y comenzar con la rehabilitación | No | -<

### 4. Criterios de éxitos:

Para determinar el éxito de nuestro dispositivo se plantea seguir los siguientes requerimientos:
- El dispositivo deberá ser capaz de generar extensión y flexión controlada de los dedos de la mano. Además se evaluará la capacidad de los juegos interactivos de la app móvil para generar iniciativa en el usuario a seguir con la rehabilitación.
- No debe generar ningún tipo de lesión o alergia.
- Se evaluarán las siguientes escalas de satisfacción del usuario:
- System Usability Scale (SUS) > 70
- Quebec User Evaluation of Satisfaction with Assistive Technology (QUEST 2.0) > 4

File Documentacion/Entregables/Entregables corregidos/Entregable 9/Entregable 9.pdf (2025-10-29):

"Año de la recuperación y consolidación de la economía peruana"

## Universidad Peruana Cayetano Heredia - Pontificia Universidad Católica del Perú


## Facultad De Ciencias E Ingeniería Ingeniería Biomédica

Noveno entregable

### “Plan de usabilidad basado en evidencias”

Integrantes:
Rodriguéz Solano, Milagros Mariajosé Romaní León, Leonardo
Romero Guerrero, Gabriel
Salas Cano, Rodrigo Emiliano Sánchez Guevara, Ady Sebastián Seijas Rojas, Camila Andrea

Cuarto ciclo
Profesores:
Miguel Rogger Hoyos Alvitez Marco Mugaburu Celi
Shirley Pahuachon Nuñez
Fecha de entrega: 28/10/2025

### 1. Contexto de uso:

El dispositivo que se plantea desarrollar supone un diseño para pacientes con alteraciones motoras en la mano derecha por hemiplejía producto de alguna alteración neurológica con un grado de espasticidad de Ashworth 3. Está enfocado en la rehabilitación en casa con previa instrucción de uso por parte del terapista. Para el uso se insertan los dedos dentro de los recubrimientos de los dedos, también se coloca y se ajusta a la medida del paciente el soporte para muñeca y la caja electrónica por medio de velcros, luego se colocan los electrodos en los músculos flexores (musculus flexor digitorum superficialis) y extensores (musculus extensor digitorum). Finalmente debemos encender el switch de nuestra caja y esperar la conexión con la aplicación móvil.

Modelado 3D de las partes del dispositivo:
Ensamblaje caja electrónica y soporte para muñeca.


Link:
https://cad.onshape.com/documents/93b90db259101b59a2de45c1/w/74b02c7e41af1e7c9447220f/e/72258f6362772d2c5cf900aa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 9834a45d94568 (https://cad.onshape.com/documents/93b90db259101b59a2de45c1/w/74b02c7e41af1e7c9447220f/e/72258f6362772d2c5cf900aa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)

Recubrimiento para dedos y parte dorsal de la mano:


Link:
https://cad.onshape.com/documents/93b90db259101b59a2de45c1/w/74b02c7e41af1e7c9447220f/e/723aad5f5bd37ef4be2c79bd (https://cad.onshape.com/documents/93b90db259101b59a2de45c1/w/74b02c7e41af1e7c9447220f/e/723aad5f5bd37ef4be2c79bd)

### 2. Perfil del usuario:

Paciente femenino de 55 años de edad con hemiplejía espástica derecha post-ACV, mantiene la muñeca y los dedos en flexión permanente. Tiene dificultad para movilizarse y realizar actividades de vida diaria (AVD) de manera autónoma. Antes del episodio de ACV la paciente era costurera. Presenta señales mioeléctricas detectables por los sensores en los músculos flexores y extensores del antebrazo. Conserva el rango de movimiento pasivo completo en flexión, sin embargo, en extensión puede llegar como máximo a 170°. La paciente requiere que el movimiento que se realice sobre su mano al extender o flexionar sea lento y controlado para evitar espasmos. La paciente no logra movimiento de pinza fina ni de agarre funcional.

Datos de la paciente:
- Accidente cerebrovascular hace 6 meses
- Lúcida, presenta disartria leve
- Hemiplejía derecha con espasticidad de grado 3 en la escala de Ashworth
- Propiocepción alterada
- Rango de movimiento pasivo:
- Flexión: Completo
- Extensión: 170° aproximadamente

### 3. Análisis de tareas:

Tarea para uso | ¿Tarea crítica? | Justificación
Colocar los recubrimientos de los | Sí | En caso se coloquen mal los recubrimientos puede

dedos y el dorso de la mano | | causar dolor en la paciente y/o generar un rango de movimiento erróneo
Ajustar con los velcros el soporte para la muñeca | Sí | Si se realiza mal generará dolor en la paciente y la caja electrónica podría caer.
Limpiar la zona y colocar los electrodos sobre los músculos flexores y extensores del antebrazo | Sí | Si no se limpia la zona y/o ubican correctamente los electrodos, la señal que captará el sensor podría ser errónea y generar movimiento alterado.
Presionar el switch de encendido | No | -
Acceder a la aplicación móvil | No | -
Realizar el calibrado de acuerdo a las señales captadas por los sensores mioeléctricos | Sí | No realizar adecuadamente la calibración podría ocasionar alteraciones en los rangos y tipos de movimientos.
Acceder al juego disponible en la aplicación móvil y comenzar con la rehabilitación | No | -

### 4. Criterios de éxitos:

Para determinar el éxito de nuestro dispositivo se plantea seguir los siguientes requerimientos:
- El dispositivo deberá ser capaz de generar extensión y flexión controlada de los dedos de la mano. Además se evaluará la capacidad de los juegos interactivos de la app móvil para generar iniciativa en el usuario a seguir con la rehabilitación.
- No debe generar ningún tipo de lesión o alergia.
- Se evaluarán las siguientes escalas de satisfacción del usuario:
- System Usability Scale (SUS) > 70
- Quebec User Evaluation of Satisfaction with Assistive Technology (QUEST 2.0) > 4

Hardware Electronico:
Diseño esquemático del circuito electrónico:



Código:

#include <ESP32Servo.h>

#include "BluetoothSerial.h"

#define EMG1_PIN 34

#define EMG2_PIN 35

#define LED1_PIN 14

#define LED2_PIN 12

#define SERVO1_PIN 18

#define SERVO2_PIN 19

#define SERVO3_PIN 21

#define SERVO4_PIN 22

#define SERVO5_PIN 23

BluetoothSerial SerialBT;
Servo servo1, servo2, servo3, servo4, servo5;

int emg1 = 0;
int emg2 = 0;
int umbral1 = 1800;
int umbral2 = 1800;
int angulo_inicial = 90;
int angulo_flexion = 40;

int angulo_extension = 140;

void moverServos(int angulo) { servo1.write(angulo);
servo2.write(angulo);
servo3.write(angulo);
servo4.write(angulo);
servo5.write(angulo);
}

void setup() {
Serial.begin(115200);
SerialBT.begin("ESP32_EMG"); pinMode(LED1_PIN, OUTPUT); pinMode(LED2_PIN, OUTPUT); digitalWrite(LED1_PIN, HIGH);

servo1.setPeriodHertz(50); servo2.setPeriodHertz(50); servo3.setPeriodHertz(50); servo4.setPeriodHertz(50); servo5.setPeriodHertz(50);

servo1.attach(SERVO1_PIN); servo2.attach(SERVO2_PIN); servo3.attach(SERVO3_PIN); servo4.attach(SERVO4_PIN); servo5.attach(SERVO5_PIN);

moverServos(angulo_inicial); Serial.println("Sistema iniciado."); }

void loop() {
emg1 = analogRead(EMG1_PIN);
emg2 = analogRead(EMG2_PIN);

Serial.print("EMG1 (Flexor): "); Serial.print(emg1); Serial.print(" / EMG2 (Extensor): "); Serial.println(emg2);

if (emg1 > umbral1 && emg1 > emg2) { moverServos(angulo_flexion);
}
else if (emg2 > umbral2 && emg2 > emg1) { moverServos(angulo_extension);
}
else {
moverServos(angulo_inicial);

}

if (SerialBT.hasClient()) { digitalWrite(LED2_PIN, HIGH); }
else {
digitalWrite(LED2_PIN, LOW); }

delay(50);
}

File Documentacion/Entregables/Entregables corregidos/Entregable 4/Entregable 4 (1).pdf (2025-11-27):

"Año de la recuperación y consolidación de la economía peruana"

## Universidad Peruana Cayetano Heredia - Pontificia Universidad Católica del Perú


## Facultad De Ciencias E Ingeniería Ingeniería Biomédica

Cuarto entregable
“Ventajas y desventajas de los productos existentes” Integrantes:
Rodriguéz Solano, Milagros Mariajosé Romani León, Leonardo
Romero Guerrero, Gabriel
Salas Cano, Rodrigo Emiliano Sánchez Guevara, Ady Sebastián Seijas Rojas, Camila Andrea

Cuarto ciclo
Profesores:
Miguel Rogger Hoyos Alvitez Marco Mugaburu Celi
Shirley Pahuachon Nuñez
Fecha de entrega: 16/09/2025

### 1. Ficha de la enfermedad:

- Nombre de la enfermedad: Hemiplejía derecha (debido a ACV)
- Sistema afectado: Principalmente neurológico, también el sistema musculoesquelético y la comunicación (por afectación motora y del habla) [1], [2]. (https://www.zotero.org/google-docs/?UfdK55)
- Breve descripción anatómica/fisiológica: El ACV produce una interrupción del flujo sanguíneo cerebral (isquemia o hemorragia), ello causa daño en las áreas motoras del cerebro. Esto causa parálisis (hemiplejia) en el lado opuesto del cuerpo, con atrofia muscular, cambios en fibras musculares y alteraciones en la conectividad cerebral. [1], [2] (https://www.zotero.org/google-docs/?Tk1c4A)

### 2. Factores y análisis de la enfermedad:

- Factores de riesgo principales: Factores de riesgo de la hemiplejia son hipertensión, diabetes, dislipidemia, tabaquismo, edad avanzada, antecedentes cardiovasculares, sexo femenino y comorbilidades. [3] (https://www.zotero.org/google-docs/?uqrXJS) Para el caso del paciente se produjo por un ACV hemorrágico.
- Manifestaciones clínicas más relevantes: Parálisis de un hemicuerpo (derecho en este caso), debilidad muscular, espasticidad, alteraciones del habla, dolor en el área atrofiada, disfunción respiratoria y dependencia funcional. [1], [2], [3] (https://www.zotero.org/google-docs/?eT5vPb)
- Breve nota sobre el impacto funcional en la vida diaria: Alta dependencia para actividades básicas (AVD), movilidad limitada, alteración en la comunicación y calidad de vida reducida. La hemiplejia genera pérdida de autonomía, sensación de incompetencia y dificultades emocionales. [4] (https://www.zotero.org/google-docs/?GHNH1E)

### 3. Prevención, diagnóstico, tratamiento y monitoreo:

- Prevención.: Control de factores de riesgo (presión arterial, glucosa, lípidos), dieta saludable, ejercicio y abandono del tabaco. [3] (https://www.zotero.org/google-docs/?3uuBOE)
- Diagnóstico: Se observa la debilidad de los músculos dependientes del nivel afectado y la de los dependientes de los niveles inferiores ipsilateralmente, sin debilidad de los dependientes de niveles superiores. Según los los signos que presente el paciente el área de la afección varía. Sin embargo hay que recordar que diversas enfermedades, como por ejemplo la esclerosis múltiple, pueden presentarse con lesiones en varias localizaciones, con lo que debe confirmarse que el resto de signos y síntomas hallados son compatibles con la localización sospechada en un primer momento y que se explican por una única lesión.[5] (https://www.zotero.org/google-docs/?dwPRDD)
- Tratamiento (farmacológico, quirúrgico, rehabilitación):
- Farmacológico: trombolíticos (en ACV isquémico agudo), anticoagulantes, control de comorbilidades. [6] (https://www.zotero.org/google-docs/?qFQ26T)
- Quirúrgico: trombectomía mecánica en casos seleccionados.[6] (https://www.zotero.org/google-docs/?yXfalc)
- Rehabilitación: | fisioterapia, | terapia ocupacional, terapia del habla, técnicas
neurodesarrolladoras, terapia de imagen motora, estimulación eléctrica, entrenamiento respiratorio y uso de toxina botulínica para espasticidad.[1], [2] (https://www.zotero.org/google-docs/?nYjnW2)
- Monitoreo : Seguimiento clínico periódico, escalas funcionales, pruebas de imagen y evaluación de complicaciones (dolor, infecciones, caídas). [6] (https://www.zotero.org/google-docs/?tXzp9D)
4. Reflexión ingenieril (máx. 1/2 página)
- Identificar un problema concreto donde un dispositivo o tecnología biomédica pueda aportar (ejemplo: monitorización, movilidad, comunicación):
Para este caso se quiere tratar la movilidad o marcha del paciente con hemiplejia.

NOTA:
- Si bien la enfermedad del caso es el ACV hemorrágico, se decidió tratar la ficha sobre la hemiplejia, ya que los problemas que tiene la paciente son causadas por la hemiplejía post-ACV hemorrágico. Así, como el objetivo de la ficha de la enfermedad es conocer el problema y los malestares de la paciente son producidas por la hemiplejía, en este entregable se trató esta enfermedad en énfasis.

Referencias:
[1] (https://www.zotero.org/google-docs/?We5Vfr) Huang, J., Ji, J., Liang, C., Zhang, Y., Sun, H., Yan, Y., & Xing, X., “Effects of physical therapy-based rehabilitation on recovery of upper limb motor function after stroke in adults: a systematic review and meta-analysis of randomized controlled trials.”, Ann. Palliat. Med., vol. 11, núm. 2, pp. 521–531, 2021, doi: https://doi.org/10.21037/apm-21-3710.
[2] (https://www.zotero.org/google-docs/?We5Vfr) Li, S., Francisco, G., & Zhou, P., “Post-stroke Hemiplegic Gait: New Perspective and Insights.”, Front. Physiol., vol. 9, 2018, doi: https://doi.org/10.3389/fphys.2018.01021.
[3] (https://www.zotero.org/google-docs/?We5Vfr) Anwer, S., & Alghadir, A., “Incidence, Prevalence, and Risk Factors of Hemiplegic Shoulder Pain: A Systematic Review.”, Int. J. Environ. Res. Public. Health, vol. 17, 2020, doi: https://doi.org/10.3390/ijerph17144962.
[4] (https://www.zotero.org/google-docs/?We5Vfr) Gavesh Kumar Vaishnav; Janardan Patra., “Comparison of Quality of Life Between Right and Left Hemiplegic Stroke Population: A Cross-Sectional Study.”, Int. J. Innov. Sci. Res. Technol., vol. 10, núm. 5, pp. 337–343, may 2025, doi: https://doi.org/10.38124/ijisrt/25may170.
[5] (https://www.zotero.org/google-docs/?We5Vfr) I. Bilbao Villabeitia, “Protocolo diagnóstico de la hemiparesia y la hemiplejía”, Medicine (Baltimore), vol. 9, núm. 78, pp. 5033–5035, 2007.
[6] (https://www.zotero.org/google-docs/?We5Vfr) Navarrete, K., & González, C., “Hemiplegia in acute ischemic stroke: A comprehensive review of case studies and the role of intravenous thrombolysis and mechanical thrombectomy.”, Ibrain, vol. 10, pp. 59–68, 2024, doi: https://doi.org/10.1002/ibra.12146. (https://www.zotero.org/google-docs/?We5Vfr)

ENTREGABLE

### 1. Identificación de la necesidad:

La paciente presenta limitaciones significativas en la independencia de su marcha y en la realización de actividades de la vida diaria. Debido al ACV, presenta hemiplejía derecha que mantiene su mano en flexión permanente, lo que sugiere la presencia de espasticidad y dificulta un patrón correcto de la marcha, esto puede hacer que su marcha sea más lenta y tenga mayores dificultades. Según el caso clínico, la paciente utiliza un bastón de cuatro puntos para desplazarse; sin embargo, al depender de su mano izquierda para sostenerlo mientras la derecha permanece inmovilizada, su autonomía se ve comprometida. Esto la obliga a soltar el bastón para realizar cualquier actividad con la mano funcional, incrementando el riesgo de caídas por falta de equilibrio y por ende, se limita su autonomía. Por ello, decidimos centrar la intervención en la mejora de la marcha, con el fin de optimizar su movilidad, promover mayor autonomía y prevenir complicaciones secundarias derivadas de un patrón de marcha alterado.

### 2. Selección de tecnologías (Estado del arte): 2.1. ReStore Exo Suit

Institución responsable: Life Ward - Página web: https://golifeward.com Descripción: ReStore es un exoesqueleto robótico blando que ayuda con la flexión plantar y dorsiflexión durante la marcha, está pensado como un dispositivo que se utilice en sesiones de rehabilitación. El progreso y retroalimentación, se realizan a través de una aplicación para celular. Se realizaron ensayos clínicos y se evidenció su funcionamiento adecuado [1], [2].
Ventajas:
- Versátil: Se adapta al paciente y puede enfocarse en divergentes etapas de la marcha.
- Fácil de transportar.
- Los datos se recopilan en una aplicación, permite ver el progreso del paciente.
Desventajas:
- Debe ser utilizado solo bajo supervisión de un fisioterapeuta autorizado, depende de los centros de rehabilitación.


Fig 1. Componentes del ReStore Exo Suit [2]

### 2.2 HAL Lower Limb (HAL-ML05):

Institución responsable: Cyberdine care robotics - página web: https://www.cyberdyne.eu/en/
Descripción: Es un dispositivo neurológico (exoesqueleto híbrido - rígido) que ayuda a mejorar la actividad muscular de miembros inferiores paréticos o paralizados. Se utiliza durante las sesiones de rehabilitación y está pensado para el entrenamiento en cinta rodante con soporte de peso corporal (BWSTT) [3], [4].
Ventajas:
- Demostró gran eficacia al utilizarse con el sistema BWSTT en comparación con otros métodos convencionales.
- Promueve la neuroplasticidad, y da soporte al lado afectado con hemiplejía como al que no la tiene.
- Opción para integrar dispositivos auxiliares que mejoren el seguimiento y monitoreo del paciente (Monitor HAL). Desventajas:
- Tiene que utilizarse únicamente bajo supervisión de personal capacitado y un fisioterapeuta en lugares acondicionados.
- No está disponible en Perú.
- Dificultad para su traslado (mayor rigidez).


Fig. 2. HAL Lower Limb (HAL-ML05) [3]


Fig. 3 Monitor HAL [3]

Referencias:
[1] ReWalk Robotics, ReStore Exo-Suit: Info Packet for Clinicians, Marlborough, MA, USA: ReWalk Robotics, Rev. 02, Mar. 2019. [Online]. Available:
https://rewalk.com/wp-content/uploads/2021/03/ReStore-Exo-Suit_Info-Packe t-for-Clinicians-v2.pdf. (https://rewalk.com/wp-content/uploads/2021/03/ReStore-Exo-Suit_Info-Packet-for-Clinicians-v2.pdf)
[2] L. N. Awad, A. Esquenazi, G. E. Francisco, K. J. Nolan, A. Jayaraman et al., “The ReWalk ReStore™ soft robotic exosuit: a multi-site clinical trial of the safety, reliability, and feasibility of exosuit-augmented post-stroke gait rehabilitation,” J. NeuroEng. Rehabil., vol. 17, no. 1, p. 80, 18-Jun-2020, doi: 10.1186/s12984-020-00702-5.
[3] Cyberdyne Care Robotics GmbH, “HAL Lower Limb (HAL-ML05): Medical Device,” Cyberdyne – Products – Medical Device, Bochum,

Germany. [Online]. Available: https://www.cyberdyne.eu/en/products/medical-device/hal-limb.

[4] M. Sczesny-Kaiser, R. Trost, M. Aach, T. A. Schildhauer, P. Schwenkreis,
M. Tegenthoff, “A randomized and controlled crossover study investigating the improvement of walking and posture functions in chronic stroke patients using HAL exoskeleton - The HALESTRO Study (HAL-Exoskeleton STROke Study),” Frontiers in Neuroscience, vol. 13, art. 1299, 29 Mar. 2019, doi: 10.3389/fnins.2019.00259.

### 2.3 R-Gait:

El R-Gait es un robot diseñado para ayudar a las personas a volver a caminar de una manera lo más natural posible. Sirve para quienes han tenido problemas neurológicos, como un derrame cerebral o una lesión de la médula espinal. Funciona con unas placas especiales para los pies que imitan el impulso que damos con los dedos al caminar. Además, deja que la cadera se mueva con más libertad, lo que hace que la marcha sea mucho más parecida a la de una persona sana. Es especialmente útil para niños y adultos que ya pasaron la primera etapa de su recuperación y necesitan una ayuda más avanzada para rehabilitarse [1][2].
Especificaciones técnicas:
- Altura mínima del usuario: 80 cm.
- Sesión típica: entrenamiento de marcha con muchas repeticiones (hasta 1500 pasos por sesión).
- Biofeedback en tiempo real: posibilidad de ver el patrón de marcha, corregir desalineaciones, guardar reportes de marcha.
- Costo: $310,557


Fig 4. R-Gait [2]

### 2.4 Fesia Walk:

El Fesia Walk es un dispositivo pequeño y fácil de usar que ayuda a las personas que tienen dificultades para caminar, especialmente si no pueden levantar o mover bien el pie. Usa estimulación eléctrica suave para enviar señales a los músculos de la pierna y el pie, lo que ayuda a controlarlos y colocarlos correctamente al caminar. El sistema incluye una prenda de tela, unos sensores y un programa de computadora, y se puede usar tanto en terapias en clínicas como en la casa, lo que permite a los pacientes practicar de forma constante para mejorar su movilidad.[3][4][5]
Especificaciones técnicas:
- Electrodo multicampo: tiene 16 cátodos (campos de salida) y algunos ánodos, lo que permite activar distintas zonas para estimular diferentes músculos con selectividad.
- Sensor de movimiento (inercial): opcional en algunas versiones, detecta fases de la marcha (contacto, despegue) y ayuda para que la estimulación se aplique en el momento justo.
- Dimensiones y peso del estimulador: aproximadamente 26 × 52 × 76 mm, peso: 91 gramos.
- Temperaturas de operación: entre 5 °C y 40 °C. Condiciones ambientales permisibles bastante estándar para uso clínico/de ambulación.
- Protección IP 22 (protección básica contra objetos sólidos >12 mm y gotas de agua verticales; no sumergible).
- Costo: se solicita cotización con la empresa.


Fig 5. Componentes Fesia Walk [3]

Referencias:
[1] Calista Medical GmbH, “R-Gait – Restoring Gait after Neurological Diagnoses in Adults and Children,” Calista Medical, Frauenfeld, Suiza. [En línea]. Disponible en: https://www.calistamedical.ch/en/produkt/r-gait/
[2] BTL Industries, “R-Gait,” BTL Industries, [En línea]. Disponible en: https://www.btlnet.es/r-gait
[3] Fesia Technology, “Fesia Walk,” Fesia Technology, San Sebastián, España. [En línea]. Disponible en: https://fesiatechnology.com/fesia-walk/
[4] Fesia Technology, Instructions for Use: Fesia Walk, versión 6.0, octubre 2022, Donostia / San Sebastián, España. [En línea]. Disponible en: https://www.alfimed.se/Alfimed/Fesia/PDF%20Files/FesiaWalk_IFU_en_r6.pdf
[5] Fesia Technology, Wearable Technology for Neural Recovery, presentación corporativa en MEDICA 2024, Düsseldorf, Alemania, 2024. [En línea]. Disponible en formato PDF:
https://www.medica.de/vis-content/event-medcom2024.MEDICA/exh-medcom2024.3002080/MEDICA-2024-Fesia-Technology-S.L.-Paper-medcom2024.3002080-We2B BuDxTeGYvpxyrZGSpw.pdf (https://www.medica.de/vis-content/event-medcom2024.MEDICA/exh-medcom2024.3002080/MEDICA-2024-Fesia-Technology-S.L.-Paper-medcom2024.3002080-We2BBuDxTeGYvpxyrZ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)

- 5. Transcutaneous spinal cord stimulation (tSCS):

Nombre del artículo: Noninvasive spinal stimulation improves walking in chronic stroke survivors: a proof-of-concept case series.
Institución responsable: National Center for Biotechnology Information (NCBI). Breve descripción funcional: La estimulación eléctrica transcutánea de la médula espinal (tSCS) es una técnica no invasiva que aplica impulsos eléctricos a través de electrodos superficiales colocados en la piel sobre la columna. En pacientes post-ACV, se usa para modular circuitos espinales y mejorar la plasticidad neuro-muscular. Se integra como complemento de la fisioterapia convencional, con el objetivo de mejorar la fuerza, la coordinación y la capacidad de marcha. [1]
Ventajas:
-Es una alternativa menos invasiva que la estimulación epidural, evitando cirugía y complicaciones médicas.
-De los 4 participantes del grupo experimental todos mejoraron la simetría de la longitud de paso después del entrenamiento (post-tSCS), lo que indica una efectividad considerable.
Desventajas:
-Evidencia limitada, aunque los resultados son prometedores estos solo son estudios piloto con pocos pacientes, haría falta ensayos clínicos a gran escala para determinar si es útil o no la técnica.
-Aunque no requiera cirugía, se necesita un personal capacitado para usarlo.
-No todos los pacientes responden de la misma manera a la misma intensidad de los electrodos, esto debido a la variabilidad neurológica del ACV.


Fig. 6. tSCS administrada a través de electrodos [1]

[1] Y. Moon et al., «Noninvasive spinal stimulation improves walking in chronic stroke survivors: a proof-of-concept case series», Biomed Eng Online, vol. 23, p. 38, abr. 2024, doi: 10.1186/s12938-024-01231-1. (https://doi.org/10.1186/s12938-024-01231-1)
- 6. Powered ankle-foot orthosis (AFO):
Nombre del artículo: The effect of a powered ankle foot orthosis on walking in a stroke subject: a case study.

Institución: National Center of Biotechnology (NCBI)
Breve descripción funcional: Este estudio evaluó cómo un paciente post-ACV con marcha deteriorada (particularmente “foot drop” o caída del pie) se comportaba al caminar con diferentes ortesis de tobillo-pie (AFO): una ortesis motorizada (powered AFO), una ortesis de resorte posterior de pierna (“posterior leg spring”) y una ortesis de carbono. Se compararon parámetros cinemáticos y cinéticos al caminar con cada una, y sin ortesis. La ortesis motorizada provee asistencia al movimiento del tobillo, contrariamente a las otras más pasivas. [1]
Ventajas:
-La ortesis motorizada aumentó los momentos articulares en tobillo, rodilla y cadera, lo que implica mejor capacidad para generar fuerzas necesarias para la marcha.
-Mejora en capacidades funcionales: al aliviar en parte la caída del pie, se mejora la elevación del pie durante la fase de swing, lo cual puede reducir tropiezos y aumentar seguridad.
Desventajas:
-Una ortesis motorizada generalmente implica mayor complejidad técnica, posible mantenimiento, necesidad de baterías o motores, lo que puede aumentar el costo del producto.


Fig 7. powered AFO [1]

[1] A. Pourghasem, I. E. Takamjani, M. T. Karimi, M. Kamali, M. Jannesari, y I. Salafian, «The effect of a powered ankle foot orthosis on walking in a stroke subject: a case study», J Phys Ther Sci, vol. 28, n.o 11, pp. 3236-3240, nov. 2016, doi: 10.1589/jpts.28.3236. (https://doi.org/10.1589/jpts.28.3236)

Tecnología o dispositivo 7: HERO (Hand Extension Robot Orthosis Grip Glove)

### 1. Identificación de la necesidad: necesidad crítica o prioritaria que atiende el

dispositivo

Las personas que han sufrido un accidente cerebrovascular (ACV) o una lesión medular espinal suelen presentar limitaciones severas en la movilidad y fuerza de la mano, como la incapacidad de abrir o cerrar los dedos, lo que impide realizar tareas básicas de la vida diaria (alimentarse, vestirse, asearse, manipular objetos). Estas limitaciones generan dependencia, pérdida de autonomía y disminución en la calidad de vida.

El dispositivo HERO (Hand Extension Robot Orthosis Grip Glove) busca responder a esta necesidad crítica: recuperar la función de la mano y fomentar su uso en actividades cotidianas, tanto en clínica como en el hogar, ofreciendo soporte activo para abrir, cerrar y manipular objetos. Al hacerlo, no solo facilita la rehabilitación intensiva y orientada a metas, sino que también promueve la independencia funcional del paciente y su participación en la vida diaria, reduciendo el riesgo de abandono del uso de la mano afectada y las complicaciones asociadas (espasticidad, dolor, compensaciones posturales).

### 2. Análisis del dispositivo

- Nombre del artículo: Integrating hand exoskeletons into goal-oriented clinic and home stroke and spinal cord injury rehabilitation
- Nombre del dispositivo: Hand Extension Robot Orthosis Grip Glove (HERO)
- Autores / instituciones responsables: Aaron Yurkewich, Sara Ortega, José Sánchez, Rosalie H. Wang y Etienne Burdet. Participaron el Imperial College London (Reino Unido), el Centro Europeo de Neurociencias (España) y la University of Toronto (Canadá).


Fig. 1. HERO hand exoskeleton showing dorsal and palmar actuators [Adapted from A. Yurkewich *et al.*, “Integrating hand exoskeletons into goal-oriented clinic and home stroke and spinal cord injury rehabilitation,” *J. Rehabil. Assist. Technol. Eng.*, vol. 9, pp. 1–12, Sep. 2022, [Online]. Available: https://doi.org/10.1177/20556683221130970].

- Descripción funcional del dispositivo:
HERO es un exoesqueleto portátil y no anclado que asiste los movimientos de flexión y extensión de los cinco dedos, además de la abducción, aducción y oposición del pulgar. Está integrado en una órtesis de muñeca ligera con actuadores y sensores, y puede activarse mediante un botón o por movimientos rápidos del brazo detectados por un sensor inercial. Su función es facilitar la apertura, cierre y manipulación de objetos en actividades de rehabilitación y vida diaria, tanto en clínica como en casa.
- Ventajas:
- Portátil, ligero y fácil de transportar.
- Permite a pacientes con afectación severa realizar tareas funcionales y bimanuales.
- Incrementa la cantidad de repeticiones en terapia, favoreciendo la neuroplasticidad.
- Mejora la independencia y motiva al paciente.

- Recibió valoraciones positivas de pacientes y terapeutas en usabilidad y satisfacción.
- Bajo costo comparado con otros robots de rehabilitación.


Fig. 2. Daily living tasks performed without and with My-HERO. [Adapted from A. Yurkewich et al., “Myoelectric untethered robotic glove enhances hand function and performance on daily living tasks after stroke,” J. Rehabil. Assist. Technol. Eng., vol. 7, pp. 1–17, Dec. 2020. Available: https://doi.org/10.1177/2055668320964050]

- Desventajas:
- Dificultad para colocarlo en manos muy rígidas o con espasticidad.
- Fuerza de agarre limitada en ciertos objetos.
- Control por aceleración o botón a veces poco sincronizado con la intención del usuario.
- No es resistente al agua, batería con duración corta.
- Estética y confort mejorables (ej. ajuste del pulgar, marcas en la piel).
- Requiere apoyo del terapeuta o cuidador en algunos casos.

### 3. Reflexión final

1. Mejoras para futuros prototipos:
- Aumentar la fuerza y precisión del agarre.
- Incorporar control más natural mediante electromiografía o sensores de intención de movimiento.
- Mejorar ergonomía y facilidad de colocación, incluso en manos espásticas.
- Incrementar la duración de la batería y hacerlo resistente al agua.
- Integrar retroalimentación sensorial o háptica para enriquecer la percepción táctil.

2. Necesidades aún no suficientemente cubiertas:
- El dispositivo ayuda al movimiento de la mano, pero no aborda de forma completa la recuperación de la movilidad del brazo y el hombro, esenciales para la funcionalidad global del miembro superior.
- No sustituye la interacción continua con el terapeuta ni garantiza por sí mismo una recuperación prolongada.
- Aún falta cubrir de manera más robusta la accesibilidad universal (adaptaciones para diferentes niveles de severidad, tamaños de mano y contextos socioeconómicos).

Referencia (artículo utilizado):
[1] A. Yurkewich, S. Ortega, J. Sánchez, R. H. Wang, and E. Burdet, "Integrating hand exoskeletons into goal-oriented clinic and home stroke and spinal cord injury rehabilitation," Journal of Rehabilitation and Assistive Technologies Engineering, vol. 9, pp. 1–11, 2022, doi: 10.1177/20556683221130970.

Tecnología o dispositivo 8: Hand Exoskeleton System (HES)

### 1. Identificación de la necesidad: necesidad crítica o prioritaria que atiende el

dispositivo

Las personas con discapacidades motoras de la mano —por causas neurológicas como lesión medular, distrofias musculares o enfermedades neuromusculares— suelen perder fuerza, destreza y capacidad de realizar actividades básicas de la vida diaria (alimentarse, asearse, manipular objetos). Esta pérdida de función limita su independencia y calidad de vida, además de incrementar la carga de cuidadores y sistemas de salud.

El dispositivo Hand Exoskeleton System (HES) busca atender esta necesidad crítica: restaurar la función de prensión y apertura de la mano en actividades de la vida diaria y ofrecer rehabilitación en el hogar o mediante telerehabilitación supervisada. Se plantea como una herramienta portátil, usable y accesible que permite a los pacientes ejercitar y utilizar la mano de manera más natural, contribuyendo tanto a la asistencia cotidiana como a la recuperación funcional.

### 2. Análisis del dispositivo

- Nombre del artículo: Wearable Robots: An Original Mechatronic Design of a Hand Exoskeleton for Assistive and Rehabilitative Purposes
- Nombre del dispositivo: Hand Exoskeleton System (HES)
- Autores / instituciones responsables: Secciani, Brogi, Pagliai, Buonamici, Gerli, Vannetti, Bianchini, Volpe y Ridolfi. Instituciones principales: Universidad de Florencia (Italia), Fundación Don Carlo Gnocchi (Italia) y Consejo Nacional de Investigación – Instituto de Sistemas Complejos (Italia).


Fig. 1. Vista explotada del nuevo módulo de motor con sus tres capas. [Adapted from N. Secciani et al., “Wearable Robots,” Frontiers in Neurorobotics, vol. 15, Oct.
2021. | Available:
https://doi.org/10.3389/fnbot.2021.750385]


Fig. 2. Comparación de tareas de agarre con y sin el HES durante la prueba ARAT. [Adapted from N. Secciani et al., “Wearable Robots,” Frontiers in Neurorobotics, vol. 15, Oct. 2021. Available: https://doi.org/10.3389/fnbot.2021.750385]

- Descripción funcional del dispositivo:
El HES es un exoesqueleto robótico de mano totalmente portátil, ergonómico y controlado mediante señales electromiográficas de superficie (sEMG). Detecta la intención de movimiento del usuario (abrir/cerrar la mano) y asiste mecánicamente a través de un sistema de transmisión por cables y un único actuador. Puede emplearse para dos fines:
- Asistencia en actividades de la vida diaria (ADLs): ayuda al paciente a sujetar, soltar y manipular objetos.
- Telerehabilitación/Programas de ejercicios en casa: posibilita realizar ejercicios diseñados por el terapeuta en casa con registro de datos para seguimiento remoto.
- Ventajas:
- Portátil, ligero (<550 g) y económico (≈550 €).
- Fácil de usar, con interfaz ergonómica personalizada (férula anatómica en PLA).
- Intuitivo gracias al control por sEMG
- Libre de cables molestos (‘unthetered’)

- Posibilita rehabilitación domiciliaria con monitoreo remoto.
- Permite movimientos de prensión adaptables a diferentes objetos.
- Cumple criterios clave: wearabilidad, comodidad, seguridad, personalización y bajo costo.

Fig. 3. Arquitectura final del exoesqueleto portátil y completamente usable. [Adapted from N. Secciani et al., “Wearable Robots,” Frontiers in Neurorobotics, vol. 15, Oct.
2021. | Available:
https://doi.org/10.3389/fnbot.2021.750385]


- Desventajas:
- Actuación activa solamente en apertura; el cierre todavía no está totalmente asistido.
- Falta de mecanismo funcional para el pulgar, lo que limita la destreza fina.
- Movimiento independiente de los dedos aún no implementado.
- Dimensiones que dificultan su uso en espacios reducidos (ej. girar una perilla).
- Distribución de peso mejorable; puede generar incomodidad tras tiempo prolongado.
- Algunos pacientes requieren ayuda para colocarlo y retirarlo.

### 3. Reflexión final

Mejoras para futuros prototipos:
- Integrar asistencia tanto para apertura como para cierre de la mano.
- Incorporar un mecanismo funcional para el pulgar y permitir control independiente de los dedos.
- Miniaturizar componentes para mayor ergonomía y reducir peso.
- Optimizar la distribución de masa y permitir articulación libre de la muñeca.
- Mejorar la autonomía energética y robustez del sistema.

Necesidades aún no suficientemente cubiertas:

- Recuperación completa de la destreza fina (pinza, manipulación precisa).
- Inclusión de retroalimentación háptica o sensorial que enriquezca la percepción táctil.
- Accesibilidad universal para distintos grados de discapacidad y condiciones clínicas.
- Autonomía plena del paciente: actualmente algunos necesitan asistencia para colocarse el dispositivo.

Referencia (artículo utilizado):

[1] L. Secciani, A. Brogi, M. Pagliai, M. Buonamici, F. Gerli, F. Vannetti, E. Bianchini, Y. Volpe, and A. Ridolfi, "Wearable robots: An original mechatronic design of a hand exoskeleton for assistive and rehabilitative purposes," Frontiers in Neurorobotics, vol. 15, pp. 1–16, 2021, doi: 10.3389/fnbot.2021.750385.

Tecnología o dispositivo 9: FREE Walk – Exoesqueleto

Institución responsable: FREE Bionics (Taiwán)

### 1. Identificación de la necesidad: Las personas que han sufrido un accidente

cerebrovascular suelen presentar hemiparesia o debilidad marcada en miembros inferiores, lo que limita su capacidad para caminar, mantener el equilibrio y realizar actividades básicas de movilidad. Esta restricción no solo reduce la independencia y calidad de vida, sino que también incrementa la dependencia de cuidadores y los costos en salud. FREE Walk busca atender esta necesidad crítica ofreciendo un entrenamiento asistido, repetitivo y seguro, que facilita la reeducación de la marcha, la recuperación de fuerza y resistencia, y el restablecimiento de la movilidad funcional en etapas tempranas de la rehabilitación.

### 2. Descripción: FREE Walk es un exoesqueleto robótico rígido diseñado para miembros

inferiores en pacientes post-ictus con hemiparesia (<6 meses). Permite entrenar la marcha, ponerse de pie y sentarse, proporcionando asistencia mecánica en cadera y rodillas. Se combina con rehabilitación convencional, integrando hasta 3 sesiones robóticas por semana junto con 2 sesiones tradicionales. Su objetivo es aumentar la fuerza de las piernas, mejorar la movilidad funcional (velocidad, resistencia y equilibrio) y favorecer la independencia. El dispositivo incluye modos de asistencia ajustables y se adapta al nivel de capacidad del paciente, lo que lo hace útil en fases subagudas de la recuperación neurológica.

### 3. Ventajas:

- Mejora significativa en fuerza de rodilla, velocidad, distancia caminada y calidad de vida respecto a terapia convencional.
- Entrenamiento robótico fue el predictor más fuerte de progreso funcional.
- Uso de pruebas objetivas (dinamometría, 6MWT, TUG) y subjetivas (SF-12).
- No se reportaron eventos adversos, perfil de seguridad favorable.

### 4. Desventajas:

- Estudio corto (4 semanas) sin seguimiento prolongado.
- Solo aplicable a pacientes con capacidad funcional intermedia (no casos graves o leves extremos).
- Sin cegamiento, riesgo de sesgo.
- Intensidad moderada; beneficios podrían aumentar con programas más largos.
- Limitado al contexto de Taiwán, sin datos de costo ni disponibilidad internacional amplia.


Figura 8. Y.-H. Lee, L.-W. Ko, C.-Y. Hsu, and Y.-Y. Cheng, Therapeutic Effects of Robotic-Exoskeleton-Assisted Gait Rehabilitation and Predictive Factors of Significant Improvements in Stroke Patients: A Randomized Controlled Trial, Bioengineering, vol. 10, no. 5, Art. 585, May 2023. https://www.mdpi.com/bioengineering/bioengineering-10-00585/article_deploy/html/images/bioengineering-10-00585-g002.png. (https://www.mdpi.com/bioengineering/bioengineering-10-00585/article_deploy/html/images/bioengineering-10-00585-g002.png)

Referencias:

Y.-H. Lee, L.-W. Ko, C.-Y. Hsu, Y.-Y. Cheng, “Therapeutic Effects of Robotic-Exoskeleton-Assisted Gait Rehabilitation and Predictive Factors of Significant Improvements in Stroke Patients: A Randomized Controlled Trial,” Bioengineering, vol. 10, no. 5, Art. 585, May 2023. https://www.mdpi.com/2306-5354/10/5/585?utm_source=.

Tecnología o dispositivo 10: Powered Hand Exoskeleton (Hand EO)

Institución responsable: Estudio clínico publicado en Actuators (MDPI).
Referencia: https://www.mdpi.com/2076-0825/14/2/67 (https://www.mdpi.com/2076-0825/14/2/67?utm_source=chatgpt.com)

### 1. Descripción funcional: El Powered Hand Exoskeleton es un dispositivo portátil y

motorizado que asiste la función de prensión en pacientes con ictus crónico. Funciona con dos actuadores lineales DC (12 V) que permiten la flexión y extensión de los dedos pulgar, índice y medio, generando un agarre tipo trípode. Su uso se integra en sesiones de rehabilitación de 30 minutos, combinando terapia convencional y asistencia robótica. El objetivo principal es mejorar la función distal de la mano y favorecer la recuperación motora del miembro superior.

### 2. Identificación de la necesidad: Las personas con ictus crónico suelen presentar

pérdida de fuerza, limitaciones en la apertura/cierre de la mano y dificultades en actividades básicas como alimentarse, vestirse o manipular objetos. Esto impacta de forma negativa en su independencia, calidad de vida y genera una elevada carga en cuidadores y sistemas de salud. El Powered Hand Exoskeleton busca responder a esta necesidad crítica mediante la restauración parcial de la función de agarre y la mejora de la destreza manual, constituyéndose como una herramienta accesible para entornos clínicos y potencialmente para programas de telerehabilitación

### 3. Ventajas

- Mejora significativa en la función motora de miembro superior medida por FMA-UE, especialmente en movimientos distales.
- Incremento de la destreza manual evaluada mediante el Box and Block Test.
- Diseño simplificado (actuadores lineales, control de 3 dedos) que facilita su portabilidad, reduce peso y coste.
- Intervención segura, sin reportes de efectos adversos.

### 4. Desventajas

- No se observaron mejoras significativas en la fuerza de agarre (grip strength).
- El protocolo de uso (2 sesiones por semana durante 8 semanas) puede ser insuficiente para pacientes con afectaciones severas.
- Población heterogénea en el estudio, lo que limita la generalización de resultados.
- Falta de evaluación a largo plazo posterior al programa de 8 semanas.
- Aunque simplificado, aún requiere supervisión y equipamiento específico.


Figura 9. S.-J. Yeh, Y.-C. Wang, W.-C. Fang, S.-C. Huang, and Y.-S. Yang, “Effectiveness of Powered Hand Exoskeleton on Upper Extremity Function in People with Chronic Stroke,” Actuators, vol. 14, no. 2, Art. 67, Feb. 2025https://www.mdpi.com/actuators/actuators-14-00067/article_deploy/html/images/actuato rs-14-00067-g002-550.jpg. (https://www.mdpi.com/actuators/actuators-14-00067/article_deploy/html/images/actuators-14-00067-g002-550.jpg)

Referencias:

S.-J. Yeh, Y.-C. Wang, W.-C. Fang, S.-C. Huang, and Y.-S. Yang, "Effectiveness of Powered Hand Exoskeleton on Upper Extremity Function in People with Chronic Stroke," Actuators, vol. 14, no. 2, Art. 67, Feb. 2025. https://www.mdpi.com/2076-0825/14/2/67?utm_source=.

OCSI DynaPro Flex Hand Orthosis (L3807 / L3809)

La ortesis de mano OCSI DynaPro Flex es un dispositivo médico dinámico diseñado para el tratamiento de contracturas en la muñeca, mano y dedos. Utiliza un sistema de tensión ajustable para aplicar una fuerza de estiramiento suave y progresiva a las articulaciones rígidas. Su objetivo es aumentar el rango de movimiento (ROM), reducir la espasticidad y mejorar la funcionalidad de la mano [1][2]. Su precio es de $146.99.


Fig 1 OCSI DynaPro Flex [2]

Componentes principales:

- Núcleo termoplástico que puede moldearse con calor adelantándose de 15° a 30° respecto al rango final de estiramiento cómodo de la muñeca.
- Rollos palmares de tamaño incremental para extender progresivamente las articulaciones MCP (metacarpofalángicas) y PIP (interfalángicas proximales) de los dedos.
- Correas con códigos de color para facilitar ajuste y colocación.
- Disponible en varios tamaños: niños, jóvenes y adultos, con medidas específicas de anchura MCP y largo de palma/mano.

SaeboGlove:

Es un guante de rehabilitación diseñado para ayudar a las personas que han sufrido un accidente cerebrovascular u otras lesiones neurológicas a recuperar la función de la mano. Se basa en el concepto de neuroplasticidad, es decir, la capacidad del cerebro para reorganizarse y formar nuevas conexiones [3][4][5]. Su precio es de $299.00.


Fig 2. Saebo Glove [3]

Componentes principales:

- Sistema de tensión (bandas tensoras) ubicado en las articulaciones interfalángicas de dedos y pulgar para asistir la extensión después de la flexión (agarre).
- Diseño espiral en antebrazo para mantener la muñeca en posición funcional.
- Puntas de los dedos cubiertas de silicona para mejorar la tracción al agarrar objetos.
- Forro antideslizante para minimizar migración, tejido de Lycra expandible para adaptarse cómodamente al dedo/mano. Palma expuesta para respiración y facilidad de colocación.

Referencias:
[1] Ongoing Care Solutions, Inc., “DynaPro® Flex Hand,” Ongoing Care Solutions, Inc., Disponible en: https://www.ongoingcare.com/product/dynapro-flex-hand
[2] SPS Co., “DynaPro Flex Hand,” SPSCo, Disponible en: https://www.spsco.com/dynapro-flex-hand.html
[3] Saebo, “SaeboGlove Hand Therapy Rehabilitation Glove,” Saebo, Disponible en: https://www.saebo.com/products/saeboglove?srsltid=AfmBOoq1vsaCfwpBxVvEY5KIptrD9_bhrRYAByg85I8YhKfe7A9JqTtG& (https://www.saebo.com/products/saeboglove)
[4] SPS Co., “SaeboGlove,” SPSCo, Disponible en: https://www.spsco.com/saeboglove.html
[5] Intramedic, “SaeboGlove Brochure,” Intramedic, Disponible en: https://www.intramedic.se/wp-content/uploads/2020/10/saeboglove-brochure.pdf

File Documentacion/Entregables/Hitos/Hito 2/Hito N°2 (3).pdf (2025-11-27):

# HITO N°2

Integrantes:

Fundamentos de Biodiseño

Mariajose Rodriguez (Modelado)
Leonardo Romani (electrónica)
Ady Sánchez (electrónica)
Rodrigo Salas (Modelado)
Camila Seijas (electrónica)

# ROBLEMÁTICA

La problemática esta centrada en las secuelas motoras y funcionales derivadas de un ACV hemorrágico, caracterizadas por una hemiplejía espástica derecha con marcada limitación en la movilidad y uso de la mano, alteraciones en la marcha que requieren un bastón de cuatro apoyos, y un aumento significativo del riesgo de caídas, pero manteniendo aun la cognición y comprensión preservadas; estas deficiencias comprometen su autonomía en actividades de la vida diaria, su desempeño ocupacional previo o su participación social, generando además riesgo de complicaciones secundarias como contracturas, deformidades y deterioro funcional progresivo, por lo que requiere un abordaje rehabilitador continuo e integral para mejorar su seguridad, independencia y calidad de vida.

# OLUCIÓN


Exoesqueleto de mano controlado por señales EMG asistidas por servomotores.

# ROCESO


Ajustar el dispositivo a la medida del usuario

Los sensores EMG
detectan la intencion de
movimiento del usuario

La señal activa los
servomotores, generando
tensión en los cables del
exoesqueleto y
posteriormente se
moviliza los dedos con
apertura controlada

# OCETO


# OCETO


# ODELADO


Link: https://cad.onshape.com/documents/359ccaa65875d5055d36d1b1/w/b8097a02f1b9163722c6bd12/e/9145c0cdb4a6c7cdb56c4556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

# ISEÑO SQUEMÁTICO


# ISEÑO SQUEMÁTICO


# PLICACIÓN PROPUESTA


La aplicación se basa en la mecánica del juego Flappy Bird, en la cual se controla a Flappy para atravesar diversos obstáculos. Nuestro juego se diferencia al incorporar una señal EMG: al recibirla mediante una conexión Wi-Fi y superar el umbral establecido, se permite realizar un salto y así continuar la partida. Además, se implementó un sistema de puntuación que incrementa al superar cada obstáculo, brindando al usuario una forma de retroalimentación continua.

# OCUMENTACIÓN


Mecanismo de extensión de dedos

# OCUMENTACIÓN


Prueba de componentes

# OCUMENTACIÓN


Prueba de componentes

# OCUMENTACIÓN


Ensamblaje de piezas y componentes

# OCUMENTACIÓN


Ensamblaje de piezas y componentes

# OCUMENTACIÓN


Ensamblaje de piezas y componentes

# IMITACIONES Y OLUCIONES


Puntos de presión
Medidas del usuario
Diseño compacto
Precisión y facilidad de uso
Interés de uso


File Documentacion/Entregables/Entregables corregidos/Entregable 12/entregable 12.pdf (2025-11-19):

"Año de la recuperación y consolidación de la economía peruana"

## Universidad Peruana Cayetano Heredia - Pontificia Universidad Católica del Perú


## Facultad De Ciencias E Ingeniería Ingeniería Biomédica

entregable 12

### “Pruebas de uso del prototipo de baja fidelidad según plan de usabilidad”

Integrantes:
Rodriguéz Solano, Milagros Mariajosé Romaní León, Leonardo
Romero Guerrero, Gabriel
Salas Cano, Rodrigo Emiliano Sánchez Guevara, Ady Sebastián Seijas Rojas, Camila Andrea Cuarto ciclo

Profesores:
Miguel Rogger Hoyos Alvitez Marco Mugaburu Celi|
Shirley Pahuachon Nuñez
Fecha de entrega: 18/11/2025

Sección del plan | ¿Qué hacer?
1. Contexto de uso | Es un diseño para pacientes con alteraciones motoras en la mano derecha por hemiplejía producto de alguna alteración neurológica con un grado de espasticidad de Ashworth 3. Para el uso se insertan los dedos dentro de los recubrimientos de los dedos, también se coloca y se ajusta a la medida del paciente el soporte para muñeca y la caja electrónica por medio de velcros, luego se colocan los electrodos en los músculos flexores y extensores. Finalmente debemos encender el switch de nuestra caja y esperar la conexión con la aplicación móvil.
2. Perfil de usuario | Paciente femenino de 55 años de edad con hemiplejía espástica derecha post-ACV, mantiene la muñeca y los dedos en flexión permanente. Tiene dificultad para movilizarse y realizar actividades de vida diaria (AVD) de manera autónoma. Antes del episodio de ACV la paciente era costurera. Presenta señales mioeléctricas detectables por los sensores en los músculos flexores y extensores del antebrazo. Conserva el rango de movimiento pasivo completo en flexión, sin embargo, en extensión puede llegar como máximo a 170°. La paciente requiere que el movimiento que se realice sobre su mano al extender o flexionar sea lento y controlado para evitar espasmos. La paciente no logra movimiento de pinza fina ni de agarre funcional.
3. Análisis de tareas | *Tabla insertada al final
4. Criterios de éxito | Para determinar el éxito de nuestro dispositivo se plantea seguir los siguientes requerimientos: - El dispositivo deberá ser capaz de generar extensión y flexión controlada de los dedos de la mano. Además se evaluará la capacidad de los juegos interactivos de la app móvil para generar iniciativa en el usuario a seguir con la rehabilitación. - No debe generar ningún tipo de lesión o alergia.
1. Modelado 3D:


link:
https://cad.onshape.com/documents/93b90db259101b59a2de45c1/w/74b02c7e41af1e7c9447220f/e/72258f6362772d2c5cf900aa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 68 (https://cad.onshape.com/documents/93b90db259101b59a2de45c1/w/74b02c7e41af1e7c9447220f/e/72258f6362772d2c5cf900aa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)
2. Datos del paciente:
- Accidente cerebrovascular hace 6 meses
- Lúcida, presenta disartria leve
- Hemiplejía derecha con espasticidad de grado 3 en la escala de Ashworth
- Propiocepción alterada
- Rango de movimiento pasivo:
- Flexión: Completo
- Extensión: 170° aproximadamente
3. Análisis de tareas:
Tarea para uso | ¿Tarea crítica? | Justificación
Colocar los recubrimientos de los dedos y el dorso de la mano | Sí | En caso se coloquen mal los recubrimientos puede causar dolor en la paciente y/o generar un rango de movimiento erróneo
Ajustar con los velcros el soporte para la muñeca | Sí | Si se realiza mal generará dolor en la paciente y la caja electrónica podría caer.
Limpiar la zona y colocar los electrodos sobre los músculos flexores y extensores del antebrazo | Sí | Si no se limpia la zona y/o ubican correctamente los electrodos, la señal que captará el sensor podría ser errónea y generar movimiento alterado.
Presionar el switch de encendido | No | -
Acceder a la aplicación móvil | No | -
Realizar el calibrado de acuerdo a las señales captadas por los sensores mioeléctricos | Sí | No realizar adecuadamente la calibración podría ocasionar alteraciones en los rangos y tipos de movimientos.

Acceder al juego
disponible en la
aplicación móvil y
comenzar con la
rehabilitación
No | -<

*Tabla insertada
4. Tabla con métricas objetivo:
Eficacia | La colocación correcta de los Myoware (encontrar los músculos correctos) está en proceso.
Eficiencia | Colocación <10 min (mayor tiempo en la colocación de los Myoware)
Satisfacción | Todavía no se probó al usuario
Seguridad | No se presentaron lesiones hasta el momento

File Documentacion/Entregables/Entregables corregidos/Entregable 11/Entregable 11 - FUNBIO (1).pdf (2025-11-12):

"Año de la recuperación y consolidación de la economía peruana"

## Universidad Peruana Cayetano Heredia - Pontificia Universidad Católica del Perú


## Facultad De Ciencias E Ingeniería Ingeniería Biomédica

Undécimo entregable
“Integración hardware - Software - Manufactura digital”

Integrantes:
Rodriguéz Solano, Milagros Mariajosé Romaní León, Leonardo
Romero Guerrero, Gabriel
Salas Cano, Rodrigo Emiliano Sánchez Guevara, Ady Sebastián Seijas Rojas, Camila Andrea Cuarto ciclo

Profesores:
Miguel Rogger Hoyos Alvitez Marco Mugaburu Celi|
Shirley Pahuachon Nuñez
Fecha de entrega: 11/11/2025

### 1. Verificación de diseño Software:

Aplicación para mejorar la neuroplasticidad e incentivar la terapia de rehabilitación del paciente a partir de la señal EMG.

Funcionalidad | Cumplimiento
Sí | No
Inicio y registro de usuario | Sí
Selección de modo de juego | | No
Guardado de progreso | Sí
Ejercicios de movimiento controlado | Sí
Recompensas visuales/auditivas | Sí
Visualización de “neuronas conectadas” | | No
Reporte de progreso gráfico | | No
Panel de terapeuta | Sí
Conexión con dispositivos externos | | No

### 2. Verificación de diseño Hardware:

Dispositivo de rehabilitación para pacientes con hemiplejía con espasticidad de Ashworth 3.

Requerimiento de Diseño | Resultado del Test
El dispositivo sumado al sistema debe tener un peso máximo de 300 gramos para no causar molestias. | La caja procesadora con el sistema incluido tiene un peso de 160 gramos. El dorso junto con las partes de los dedos tienen un peso total de 150,39 gramos.
El soporte de muñeca debe ser regulable y adaptable. | El soporte es adaptable al antebrazo del usuario con velcros.
Debe ser intuitivo y mostrar el estado en | Tiene un botón de encendido y apagado,

el que se encuentra el dispositivo. | además de luces led que indican el estado del dispositivo.
El dispositivo no debe generar alergias o algún tipo de daño al estar en contacto con la piel. | El material con el que tiene contacto el usuario no tiene zonas afiladas, además que tiene protectores para evitar molestias.
La batería del dispositivo debe de durar con energía un mínimo de 3 horas. | La batería de litio tardará aproximadamente 1 hora en descargarse por completo, esto podría dificultar un poco la independencia del dispositivo al requerir conexión frecuente a una fuente de energía.
La caja procesadora debe ser pequeña y compacta. | La caja procesadora tiene un largo total de 10,8 cm por 4,5 cm de ancho, además de un alto de 6 cm.

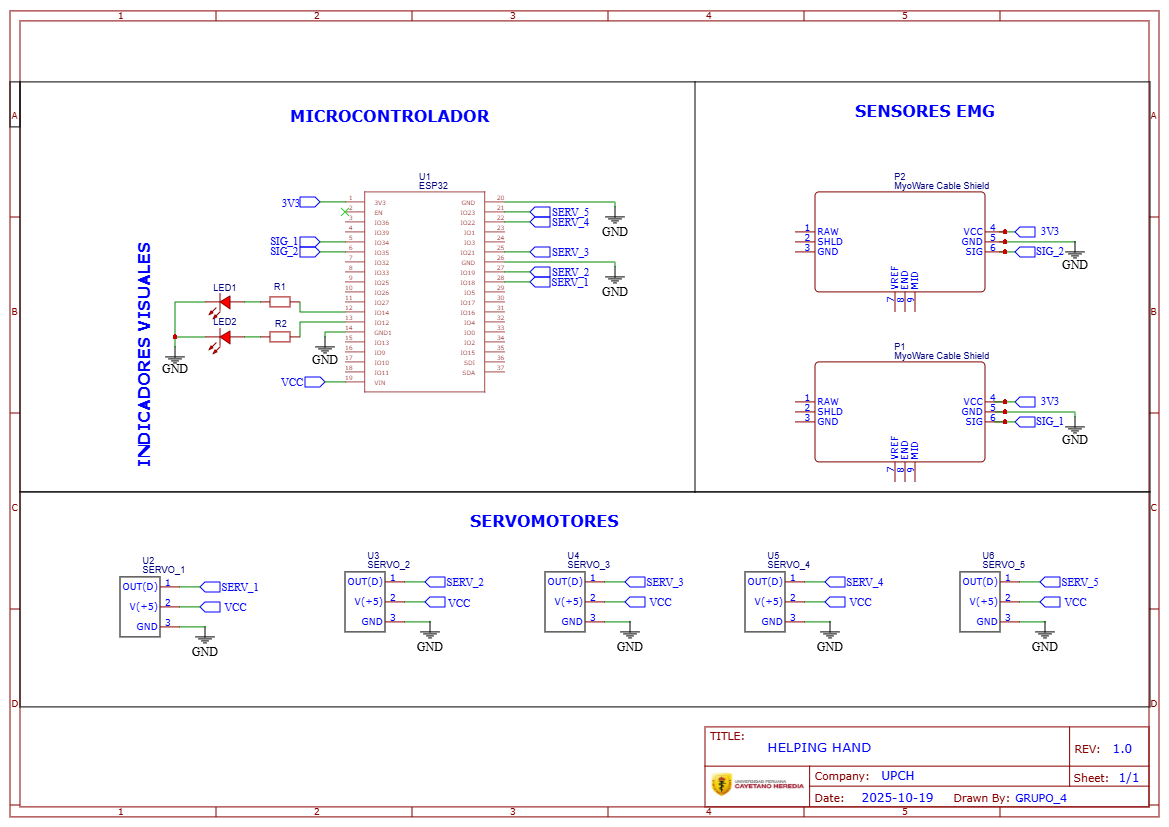
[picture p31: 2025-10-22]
Documentacion/Entregables/Entregables corregidos/Entregable 8/Esquema electrónico/Schematic_GRUPO4_2025-10-21 (1) (1).png

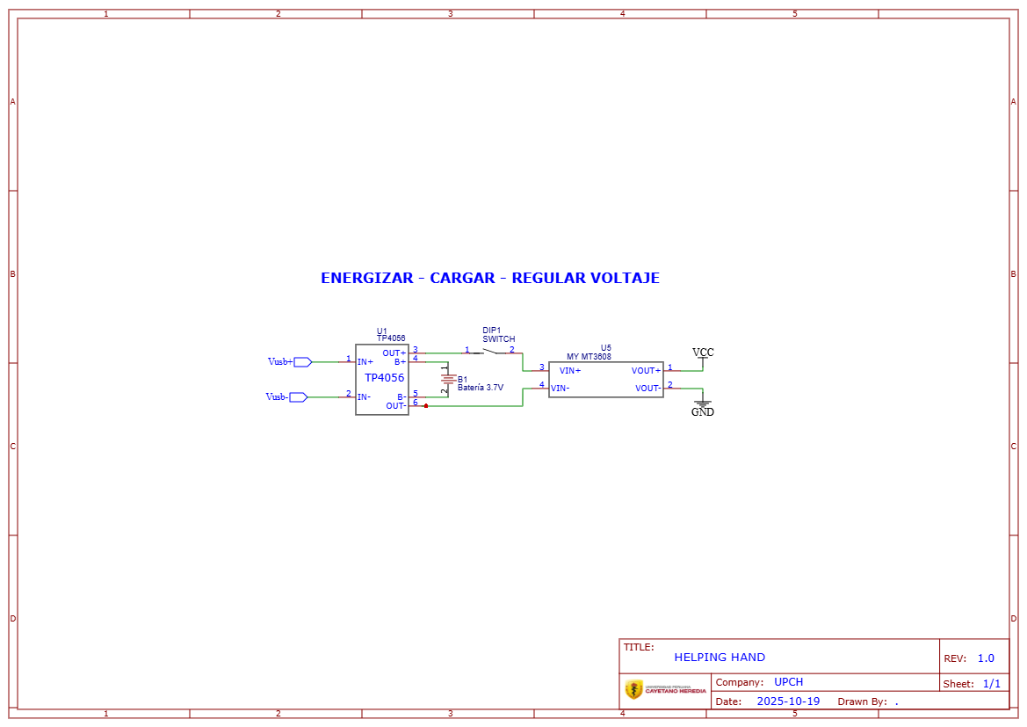
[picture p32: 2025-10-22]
Documentacion/Entregables/Entregables corregidos/Entregable 8/Esquema electrónico/Schematic_GRUPO_4.2_2025-10-21 (1) (1).png

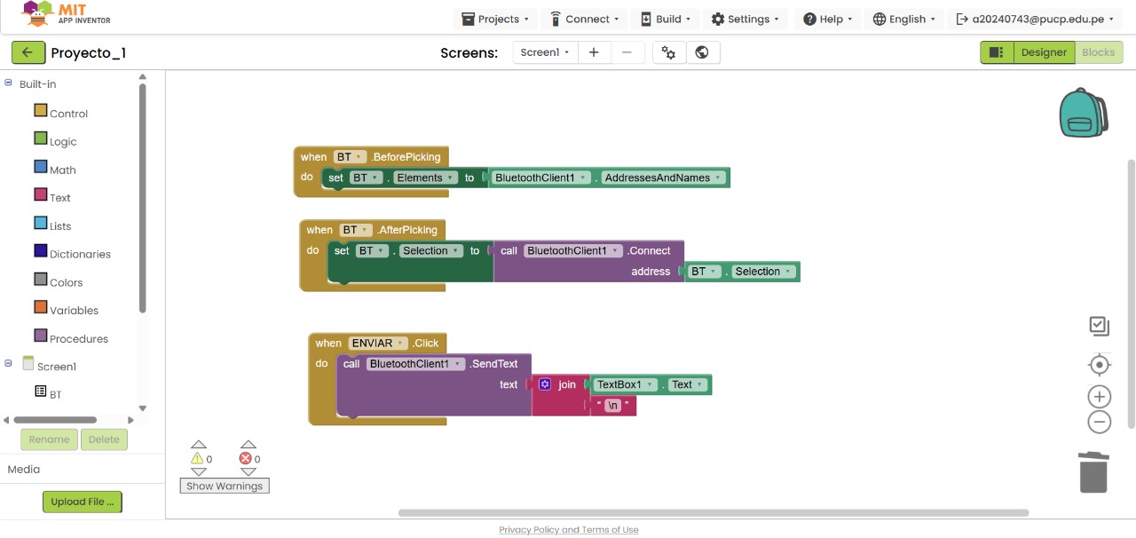
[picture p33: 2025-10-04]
Documentacion/Talleres/Taller 02.10.25/Proyecto 1/BLOQUES.jpg

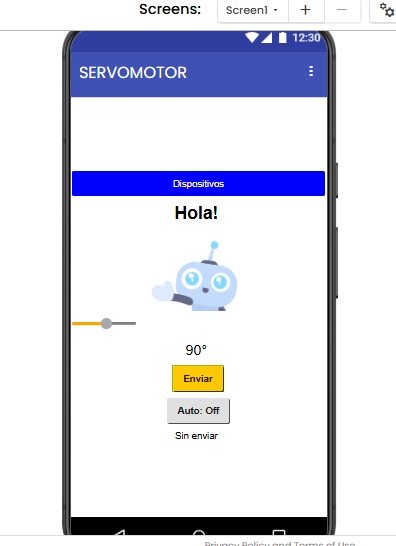
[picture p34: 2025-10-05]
Documentacion/Talleres/Taller 02.10.25/Proyecto 2/app2.jpg

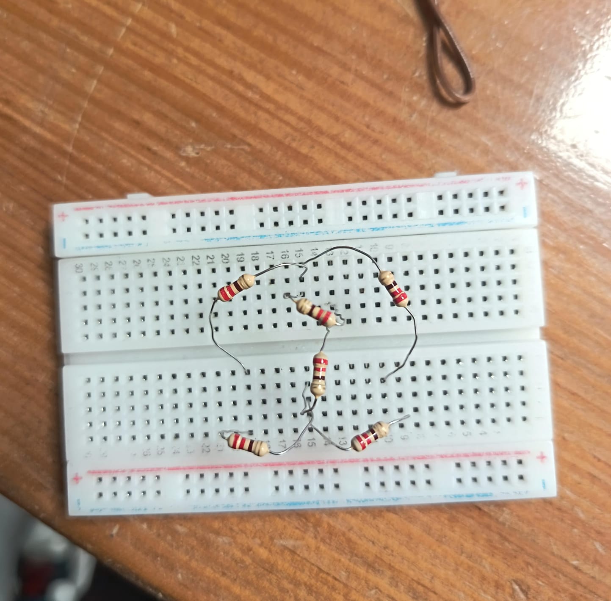
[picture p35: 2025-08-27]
Documentacion/Talleres/Taller de electrónica/T2/dragón horizontal.jpg

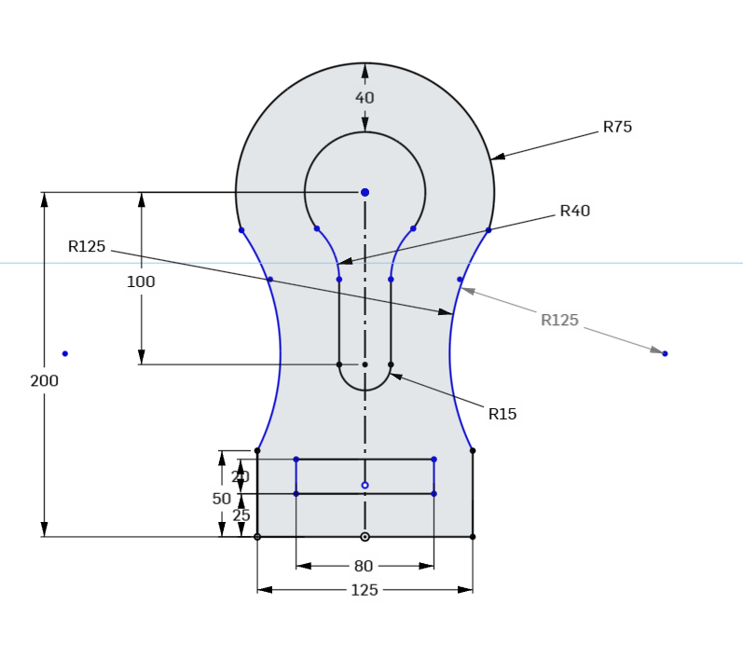
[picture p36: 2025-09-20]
Documentacion/Talleres/Taller 5 Modelado 3D/Leonardo Romaní/Taller modelado 3D.png

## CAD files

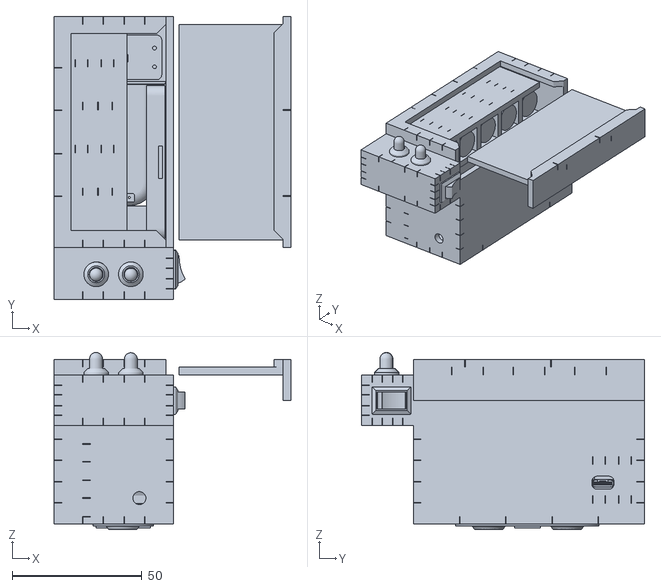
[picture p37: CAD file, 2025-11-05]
Documentacion/Entregables/Entregables corregidos/Entregable 10/Assembly 2.stl
91.2 x 109.0 x 68.2

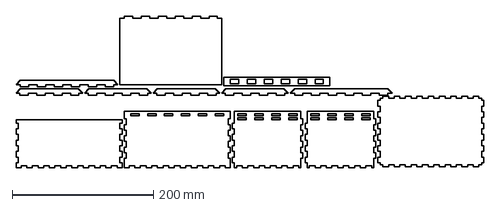
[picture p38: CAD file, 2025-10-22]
Documentacion/Entregables/Entregables corregidos/Entregable 8/Caja-piezas-funbio (1).dxf
662.0 x 215.0 mm

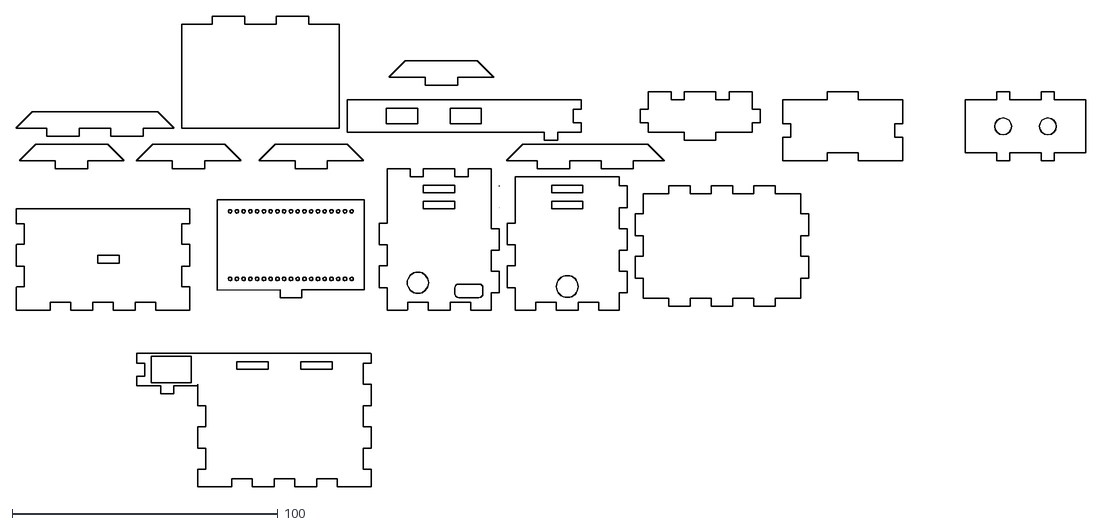
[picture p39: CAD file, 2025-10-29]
Documentacion/Entregables/Entregables corregidos/Entregable 9/Caja_electronica_corte_laser.dxf
402.1 x 177.1

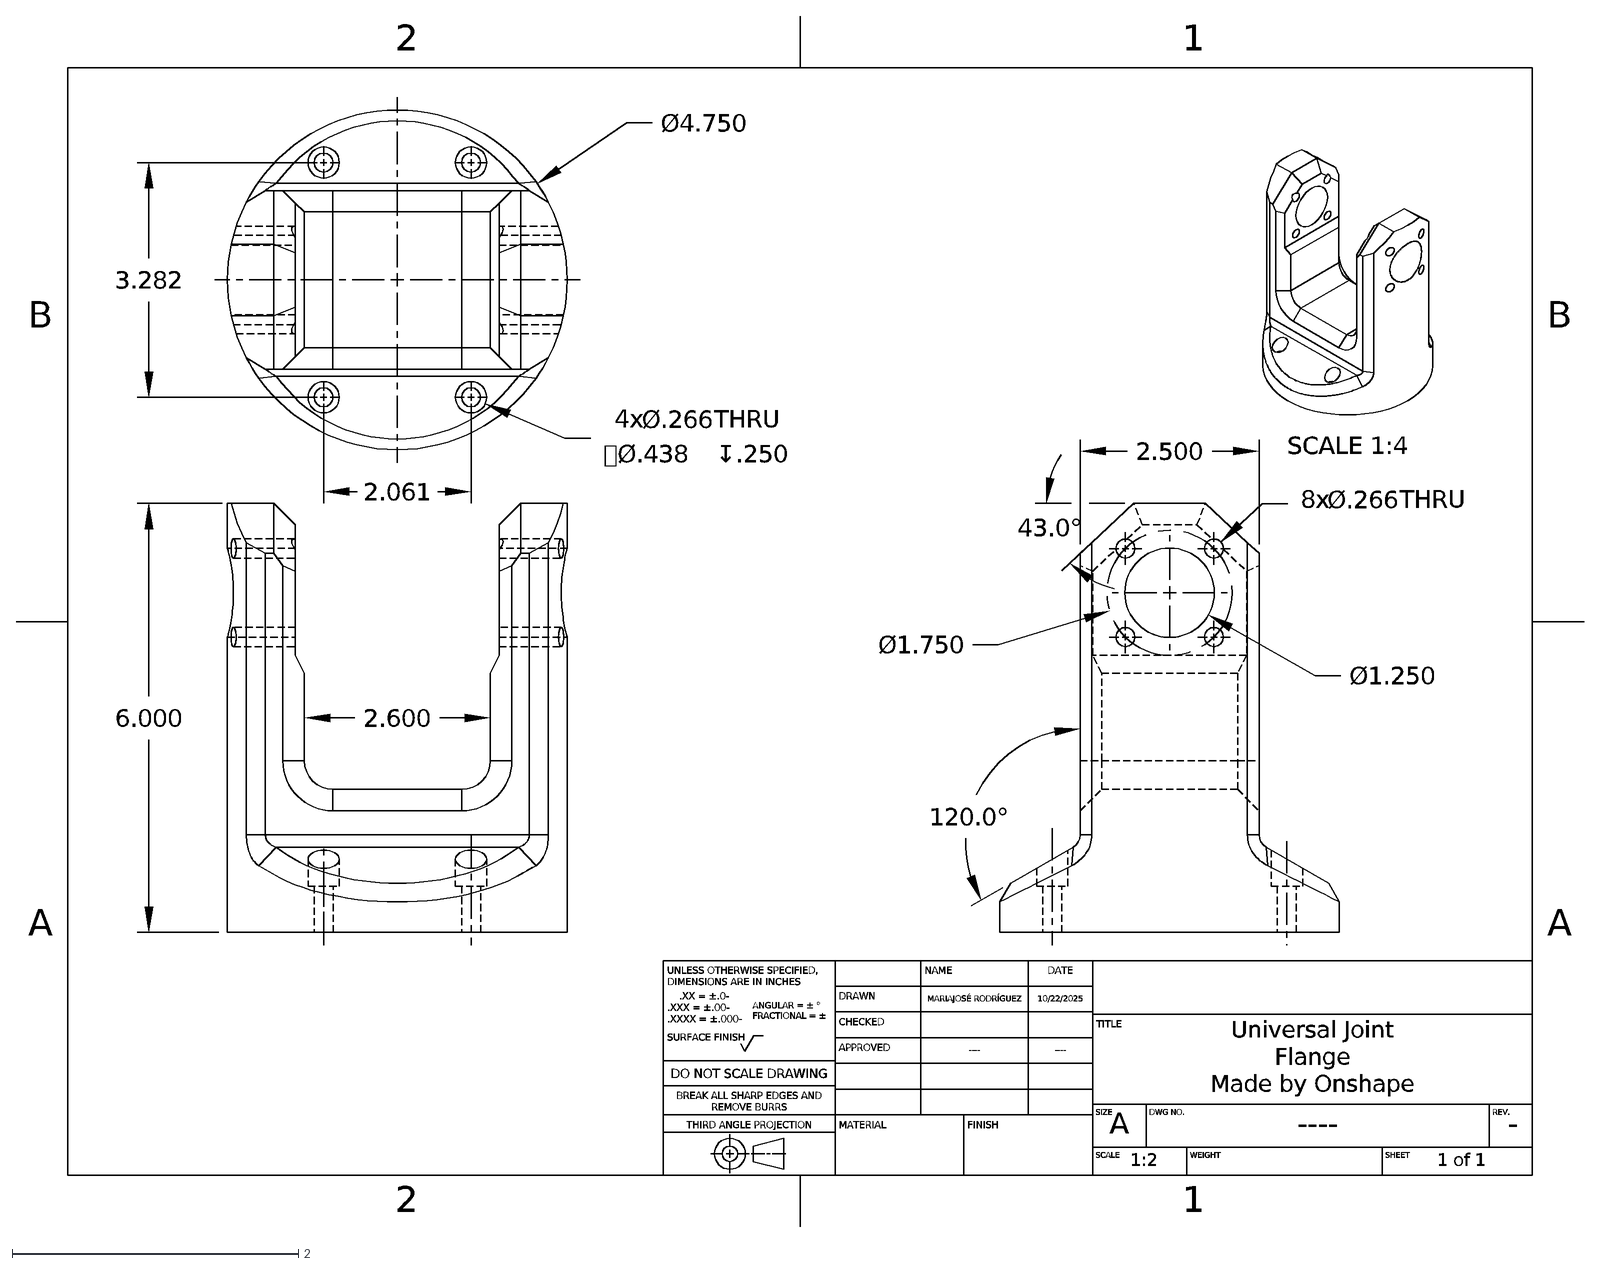
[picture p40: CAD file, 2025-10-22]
Documentacion/Talleres/Taller 22.10.25/Ejemplo 4/Corte Láser (1).dxf
2
1
A
B
UNLESS OTHERWISE SPECIFIED, DIMENSIONS ARE IN INCHES
.XX = ±.0- .XXX = ±.00- .XXXX = ±.000-
ANGULAR = ± ° FRACTIONAL = ±
SURFACE FINISH
DO NOT SCALE DRAWING
BREAK ALL SHARP EDGES AND REMOVE BURRS
THIRD ANGLE PROJECTION
NAME
DATE
DRAWN
MARIAJOSÉ RODRÍGUEZ
10/22/2025
CHECKED
APPROVED
----
MATERIAL
FINISH
TITLE
Universal Joint
Flange
Made by Onshape
SIZE
DWG NO.
REV.
-
SCALE
1:2
WEIGHT
SHEET
1 of 1
SCALE 1:4
8x
Ø.266
THRU
4x
Ø4.750
Ø1.750
Ø1.250
6.000
2.600
2.061
3.282
2.500
120.0°
43.0°

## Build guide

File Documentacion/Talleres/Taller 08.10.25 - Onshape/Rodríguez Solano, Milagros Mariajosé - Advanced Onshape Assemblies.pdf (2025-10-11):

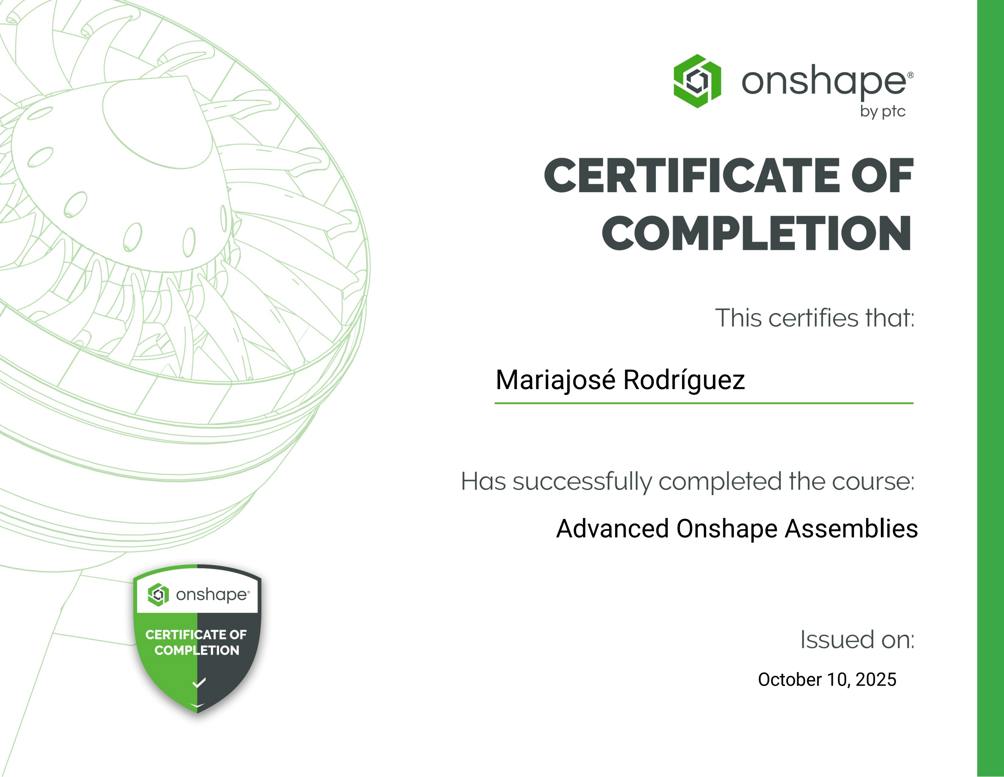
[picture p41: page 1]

Mariajosé Rodríguez

Advanced Onshape Assemblies

October 10, 2025

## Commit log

2025-08-26 Rename Lesión en la Médula Espinal (LME).md to Fichas informativas.md
2025-09-04 Create Actividad 2: código en Arduino IDE
2025-09-04 Create Actividad 1: código Arduino IDE
2025-09-04 Create Actividad 3: código Arduino IDE
2025-09-11 Create Actividad 1: Código y link de video
2025-09-11 Create Actividad 2: código y link de video
2025-09-11 Create Actividad 3: código y link de video
2025-09-20 Add files via upload
    https://cad.onshape.com/documents/90d72d8061fd5d20db5250ec/w/b80550de5bd6a1fed38f7bec/e/c95a2f2b8ec4909e37a52099
2025-10-11 Rename Milagros Mariajosé Rodríguez Solano - Advanced Onshape Assemblies.pdf to Rodríguez Solano, Milagros Mariajosé - Advanced Onshape Assemblies.pdf
